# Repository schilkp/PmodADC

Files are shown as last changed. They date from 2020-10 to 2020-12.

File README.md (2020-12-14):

# PmodADC

### Philipp Schilk, 2020

## Description
A fully discrete 14bit, 41kHz, Successive-Approximation Audio ADC and 14bit 41kHz R2R Audio DAC 
controlled by an [iCEBreaker FPGA board](https://1bitsquared.com/collections/fpga/products/icebreaker). 

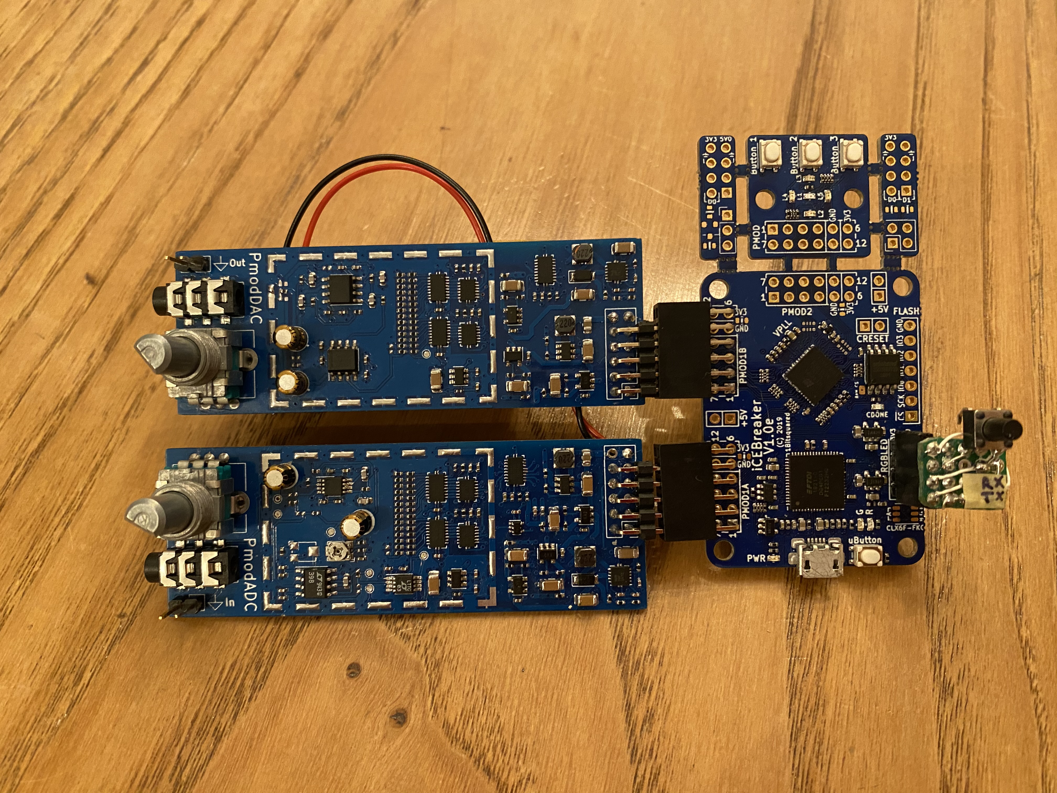
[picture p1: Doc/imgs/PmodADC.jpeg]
Overview


## Details

## Demos

These are a few demonstrations of the PmodADC and PmodDAC.

For each song, there are 3 files provided:  
    - The original (mono) wav file  
    - The song played back via a phone and recorded on the PmodADC  
    - The song played via the PmodDAC and recorded with a Focusrite Saffire Pro 40 Interface.  

Note that all audio files are provided at 44.1kHz to allow for easier playback:  
The PmodADC demos were played back at 44.1kHz and upsampled from 41kHz after recording.  
The PmodDAC demos were downsampled to 41kHz for playback, and recorded at 44.1kHz.   

All music by Kevin MacLeod, see Music Attribution below.

The wav files can be found [here](Doc/Demos), or via the Soundcloud links below:

| *Song* 	| *Original* 	| *PmodADC Demo* 	| *PmodDAC Demo* 	|
|:-:	|:-:	|:-:	|:-:	|
| New Hero in Town 	| [here](https://soundcloud.com/user-489490213/new-hero-in-town-reference/s-YKGpP2wkpSc) 	| [here](https://soundcloud.com/user-489490213/new-hero-in-town-pmodadc/s-A1OPIKn5Tv4) 	| [here](https://soundcloud.com/user-489490213/new-hero-in-town-pmoddac/s-smGRP41zKKE) 	|
| Protofunk 	| [here](https://soundcloud.com/user-489490213/protofunk-reference/s-mYtDzv4H0rD) 	| [here](https://soundcloud.com/user-489490213/protofunk-pmodadc/s-5CrWlwWIQJU) 	| [here](https://soundcloud.com/user-489490213/protofunk-pmoddac/s-AqIKrZKs7Aa) 	|
| Whiskey on the Mississippi 	| [here](https://soundcloud.com/user-489490213/whiskey-on-the-mississippi-reference/s-0ekaJDO2ERm) 	| [here](https://soundcloud.com/user-489490213/whiskey-on-the-mississippi-pmodadc/s-d2xfiT4uBGa) 	| [here](https://soundcloud.com/user-489490213/whiskey-on-the-mississippi-pmoddac/s-CflAaRhN0gA) 	|
| The Parting 	| [here](https://soundcloud.com/user-489490213/the-parting-reference/s-s09MCjP3SIX) 	| [here](https://soundcloud.com/user-489490213/the-parting-pmodadc/s-gcHSaS2ZzWT) 	| [here](https://soundcloud.com/user-489490213/the-parting-pmoddac/s-kLg3MuZsgWg) 	|

Alternatively, a single website with all the above audio files can be found [here](https://soundcloud.com/user-489490213/sets/pmodadc-demonstration/s-fJryQAe7XSp).

## Setup

A guide to setting up the open-source [apio](https://github.com/FPGAwars/apio) tool-chain can be found [here](Doc/ToolchainSetup.md).   

This project requires some hardware modifications to the iCEbreaker board. See [here](Doc/iCEBreakerMod.md) for details.  

The Python/Matlab scripts to play and record audio require some drivers and setup. See [here](Doc/FT2232H_Setup.md) for details.  

Two versions of the Verilog Code are provided:  
	- Setup 1, which immediately plays back the audio recorded by the PmodADC via the PmodDAC.  
	- Setup 2, which allows the PmodADC and PmodDAC to send/receive audio via USB.
	
See [here](iCEbreaker_HDL/Setup%20Description.md) for details.

## Python Utilities

The easiest way to record and play music is using the two python utilities provided [here](Scripts/Python/).

They rely on numpy, pyserial, wavio, and scipy:

```bash
> pip install -r requirements.txt
```

They have only been tested under python3.

### Record.py

Record music to a wav file using the PmodADC.

By default the audio is resampled to 44.1kHz.

Usage:

```
usage: Record.py [-h] (-s S | -n N | -i) [-r] comport outfile

positional arguments:
  comport     The COM port to which the board is connected.
  outfile     The filename under which the recorded audio should be saved.

optional arguments:
  -h, --help  show this help message and exit
  -s S        The number of seconds that should be recorded.
  -n N        The number of samples that should be recorded.
  -i          Recorded until a Keyboard Interrupt is received.
  -r          Do not re-sample audio to 44.1khz.
```

Record 10 seconds of audio from COM8 and save it to recording.wav:

```bash
python3 Record.py COM8 recording.wav -s 10
```

### Play.py

Play a wav file via the PmodDAC.

By default the wav file is resampled to 41kHz (if necessary). 

Usage:
```
usage: Play.py [-h] [-L | -R] [-r] comport wavfile

positional arguments:
  comport     The COM port to which the board is connected.
  wavfile     The filename of the audio file.

optional arguments:
  -h, --help  show this help message and exit
  -L          Play the left audio channel.
  -R          Play the right audio channel.
  -r          Do not re-sample audio to 41kHz.
```

Play the left channel of some_audio_file.wav via COM8:

```bash
python3 Play.py COM8 some_audio_file.wav -L
```

## Matlab Utilities

Matlab functions to communicate with the PmodADC/PmodDAC are also provided. 

See [Scripts/MATLAB/RecordAudioExample.m](Scripts/MATLAB/RecordAudioExample.m) and [Scripts/MATALB/PlayAudioExample.m](Scripts/MATALB/PlayAudioExample.m)

## Music Attribution

```
Protofunk by Kevin MacLeod  
Link: https://incompetech.filmmusic.io/song/4247-protofunk  
License: http://creativecommons.org/licenses/by/4.0/  

Whiskey on the Mississippi by Kevin MacLeod  
Link: https://incompetech.filmmusic.io/song/4624-whiskey-on-the-mississippi  
License: http://creativecommons.org/licenses/by/4.0/  
  
New Hero In Town by Kevin MacLeod  
Link: https://incompetech.filmmusic.io/song/5742-new-hero-in-town  
License: http://creativecommons.org/licenses/by/4.0/  

The Parting by Kevin MacLeod  
Link: https://incompetech.filmmusic.io/song/4501-the-parting  
License: http://creativecommons.org/licenses/by/4.0/  
```

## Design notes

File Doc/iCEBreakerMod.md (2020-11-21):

# iCEBreaker Mod
# Hardware Modifications

Everything done to the iCEBreaker board. 

(Note: This is based on my v1.0e iCEBreaker board. I don't know if this is any different for other versions)

## Isolate FIFO Interface

To be able to transmit all audio data, the FT2232H is used in FIFO mode.
Because this uses many pins in common with the PMOD2 connector, the devices on the break-off
section may interfere with the communication. 

Therefore the break-off section should either be broken-off, or the disconnected 
by removing the 2 Resistor Networks indicated below:

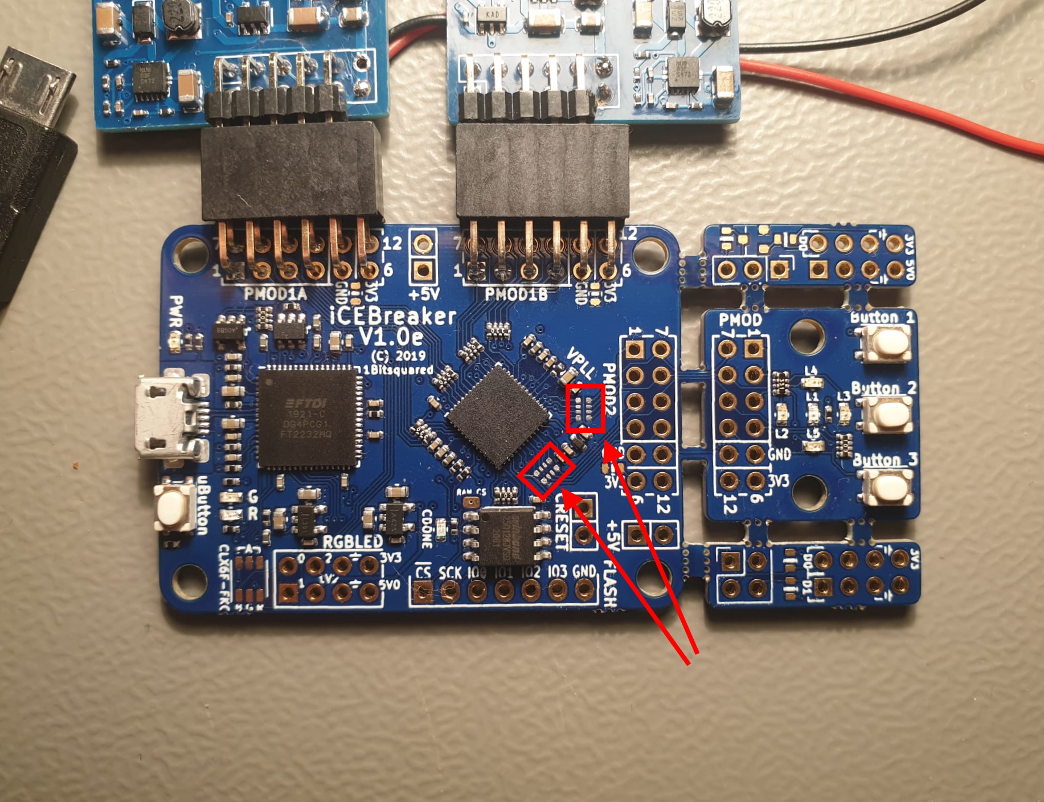
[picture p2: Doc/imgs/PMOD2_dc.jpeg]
Resistor Networks to be removed


To be fair, I don't know if this would actually be a problem. I did not test it. 

## Connect FIFO Interface

The FIFO needs to be connected to the FPGA using the (labelled) solder jumpers on the back side of the board.
Two of them are already connected by default for UART communication. 

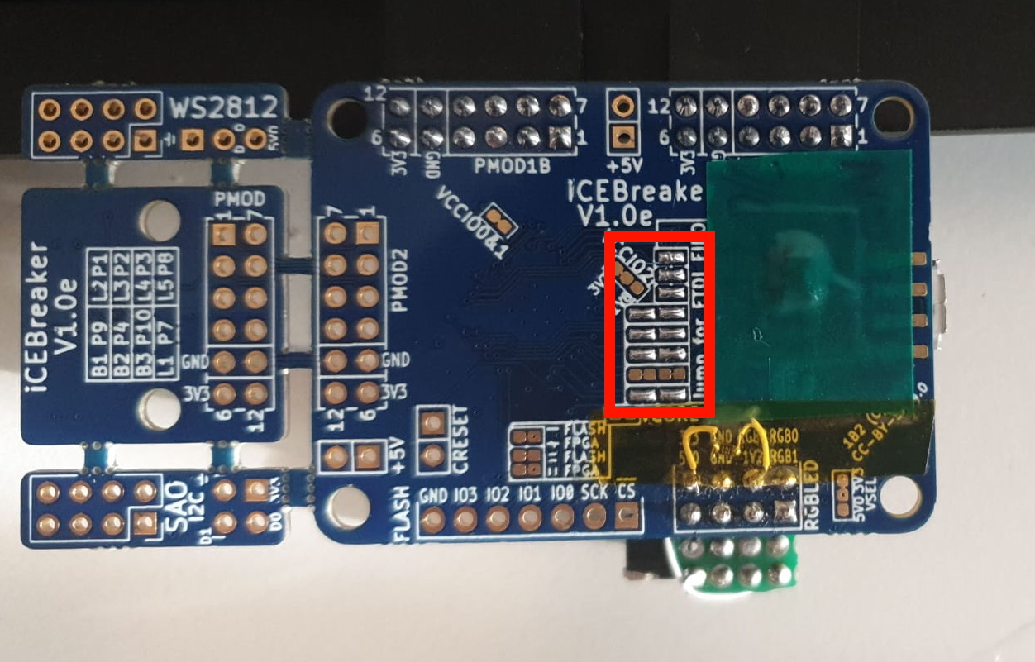
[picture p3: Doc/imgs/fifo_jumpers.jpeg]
FIFO Jumpers


## Add Reset Pull-up

Because the uButton conflicts with the FIFO interface, it cannot be used as a reset button.
As there is no other GPIO left, the RGBLED port is used for additional connectivity.

The pin to which a reset button may be connected requires a pull-up, so that the project
will still function without anything attached to this port.

A 10K pull-up between the '2' Pin and '3V3' can easily be attached to the backside:

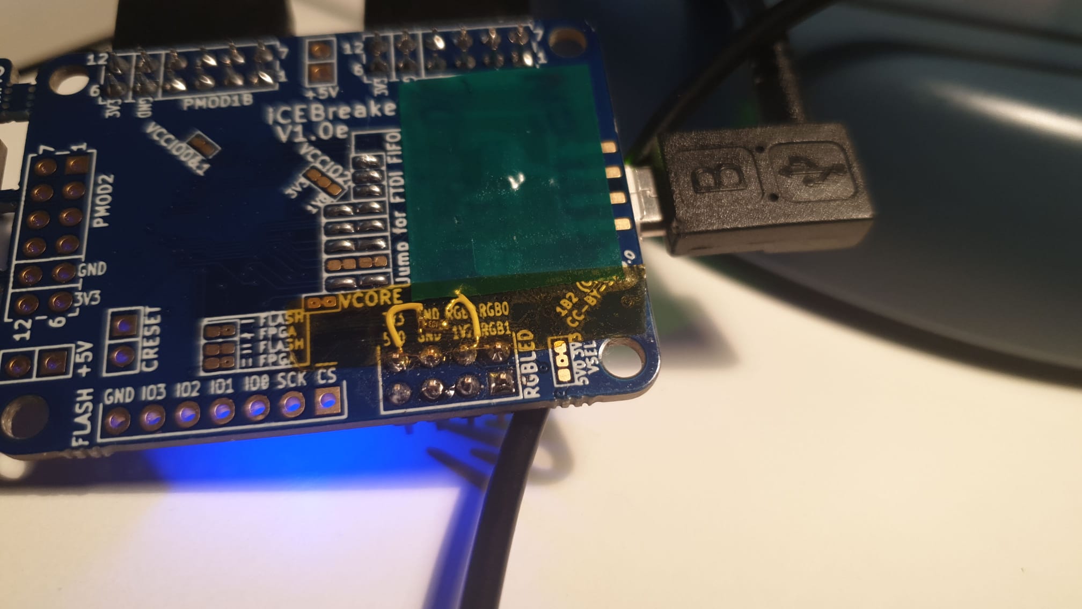
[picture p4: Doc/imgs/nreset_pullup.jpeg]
Additional 10K Pull-Up Resistor


## Optional Reset Button and Status LEDs
A small board may optionally be constructed and attached to the RGBLED connector to 
add a manual reset button and a RX Error and TX Error LED.

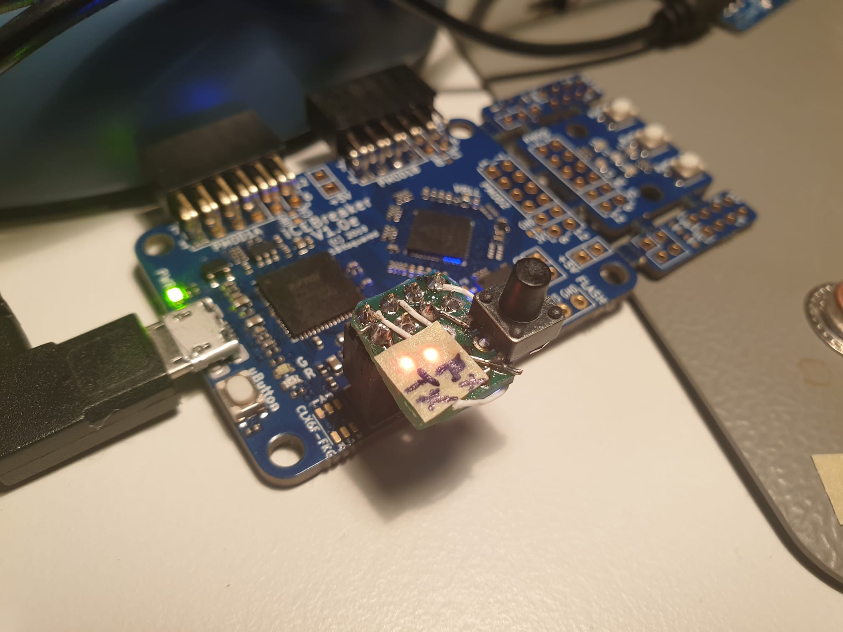
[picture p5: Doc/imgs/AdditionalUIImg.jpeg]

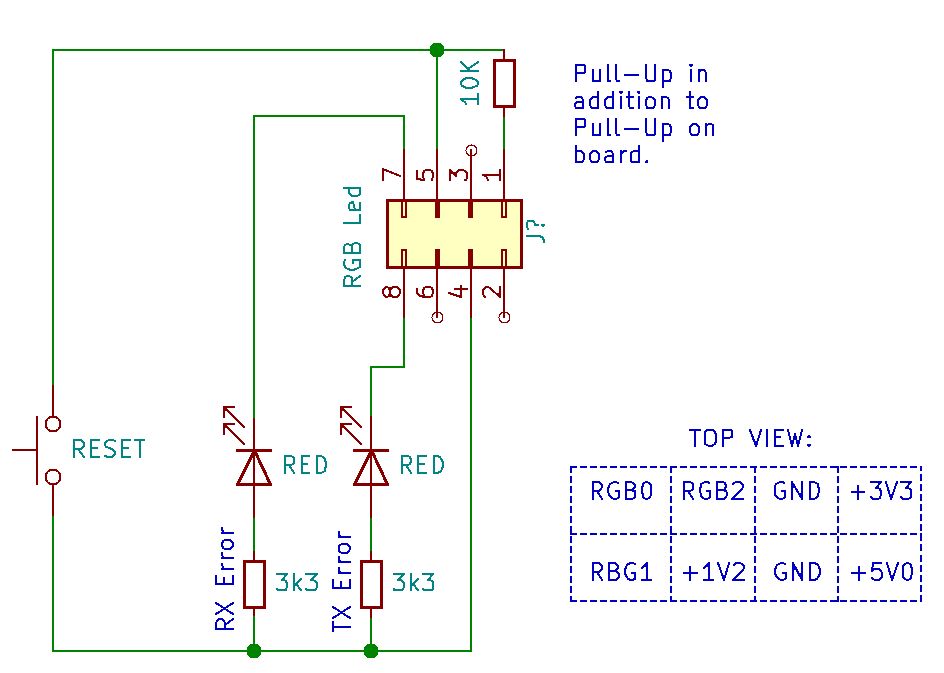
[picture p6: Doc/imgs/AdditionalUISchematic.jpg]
Schematic


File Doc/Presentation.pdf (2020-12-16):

# A DISCRETE SAR ADC/DAC

### Philipp Schilk HS2020

### P&S “iCEBreaker FPGA For IoT Sensing Systems”

### Center for Project Based Learning / ETH Zuerich

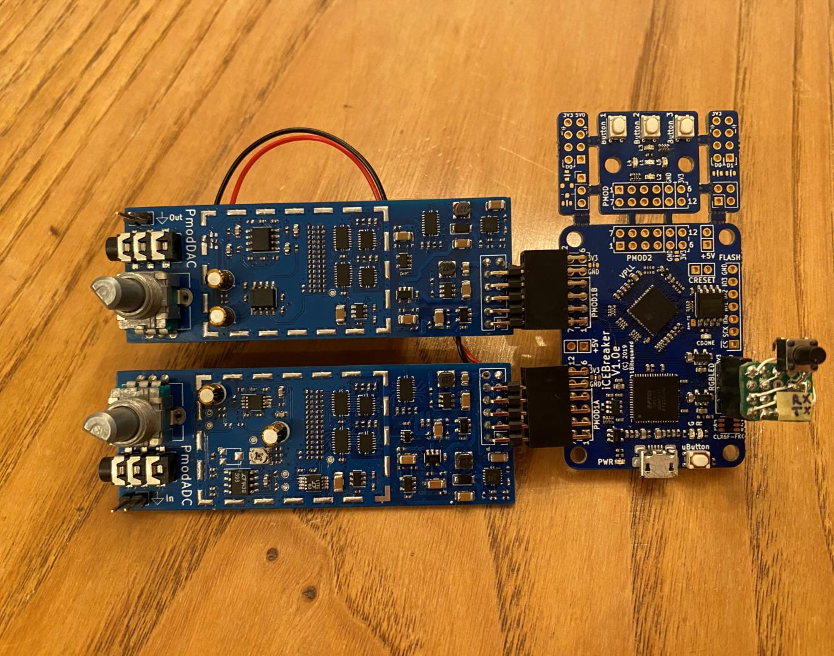
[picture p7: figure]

# Overview

- ADC and DAC
- 14bit Resolution
- 41kHz Sample Rate
- Custom Circuit and Hardware
- Realtime Bidirectional USB Communication
- Python Scripts for Recording and Playback
- MATLAB Scripts for Recording, Playback, and Characterization

# Operating Principle

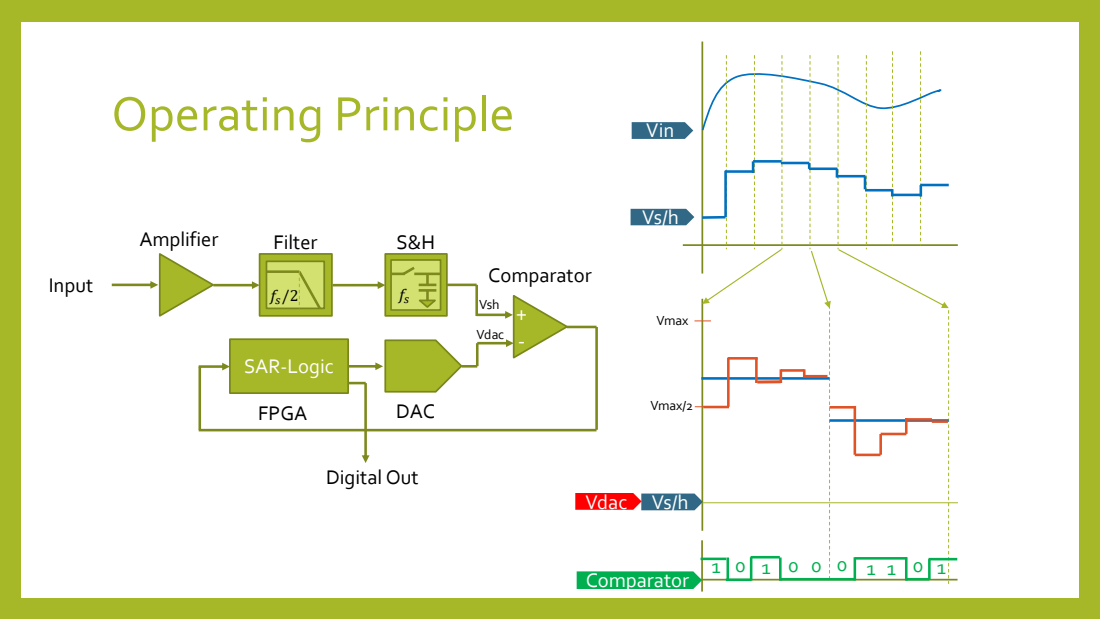
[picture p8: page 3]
Amplifier; Filter; DAC; Comparator; SAR-Logic; Input; FPGA; Digital Out; Vin; Vdac Vs/h; Vdac; Vsh; Vmax; Vmax/2

# Hardware Implementation

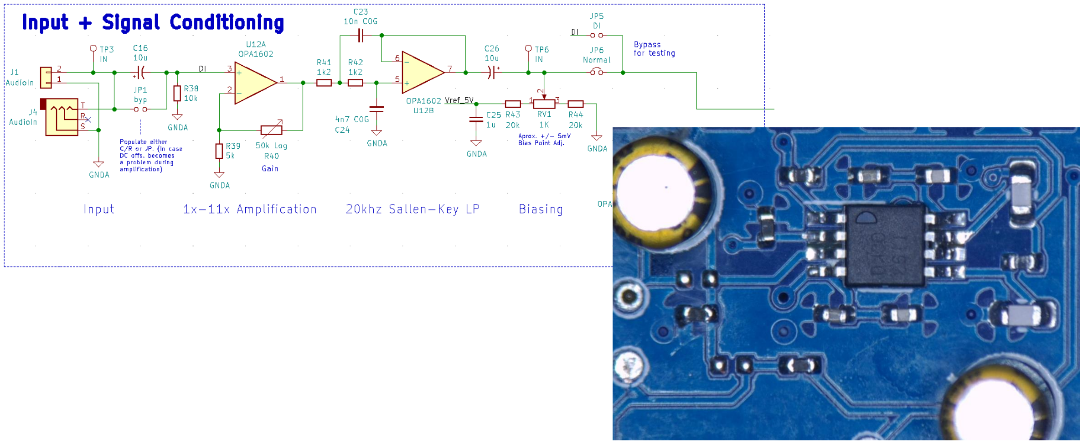
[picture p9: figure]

# Hardware Implementation

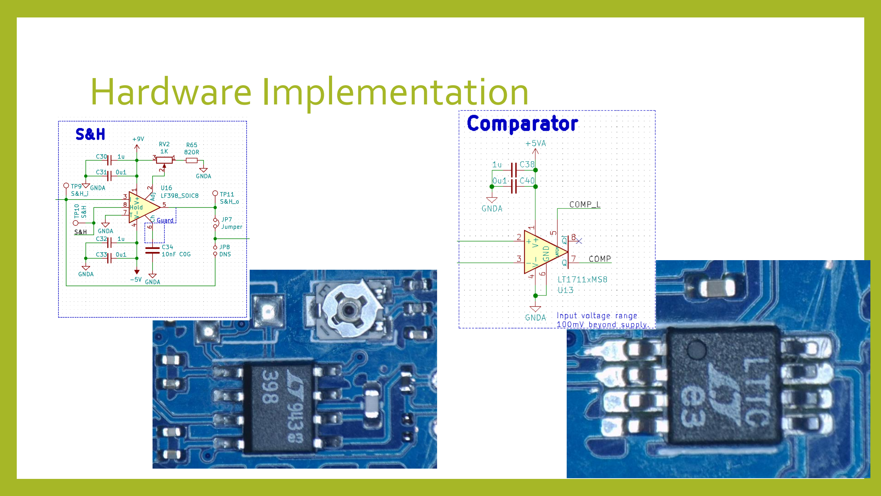
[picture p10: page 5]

# Hardware Implementation

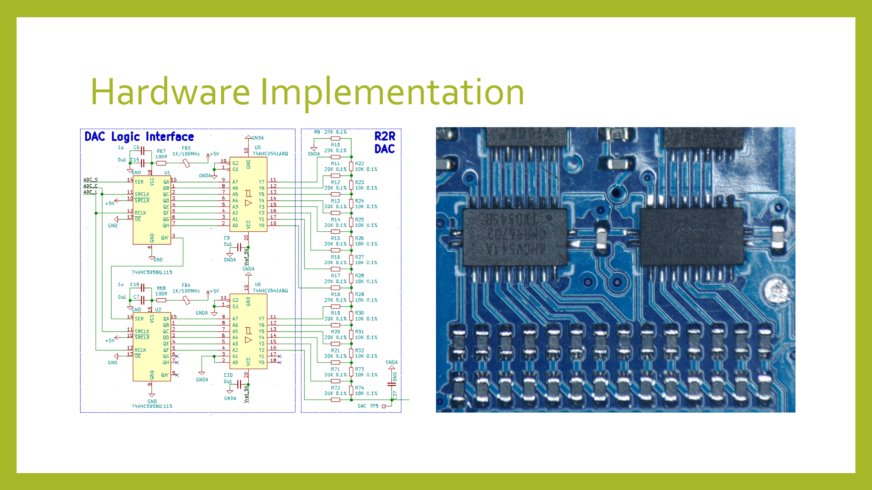
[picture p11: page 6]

# Construction

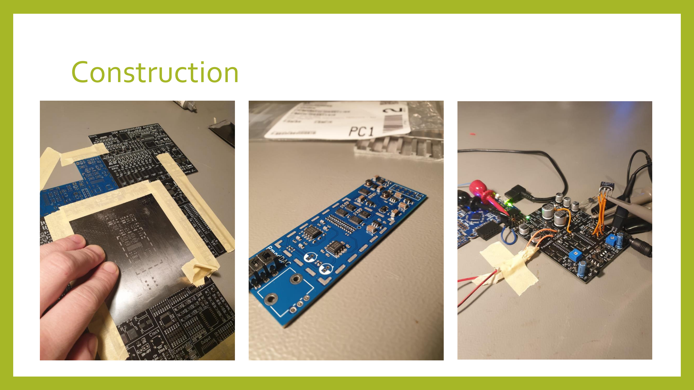
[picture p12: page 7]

# Verilog Implementation

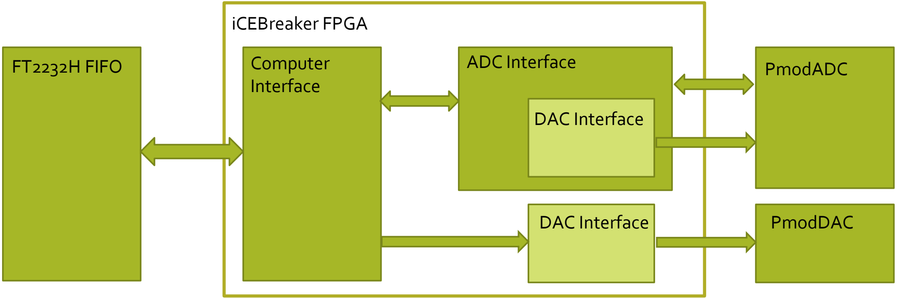
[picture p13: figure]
Computer Interface; ADC Interface; DAC Interface; PmodADC; PmodDAC; FT2232H FIFO; iCEBreaker FPGA

# Verilog Implementation: DAC Interface

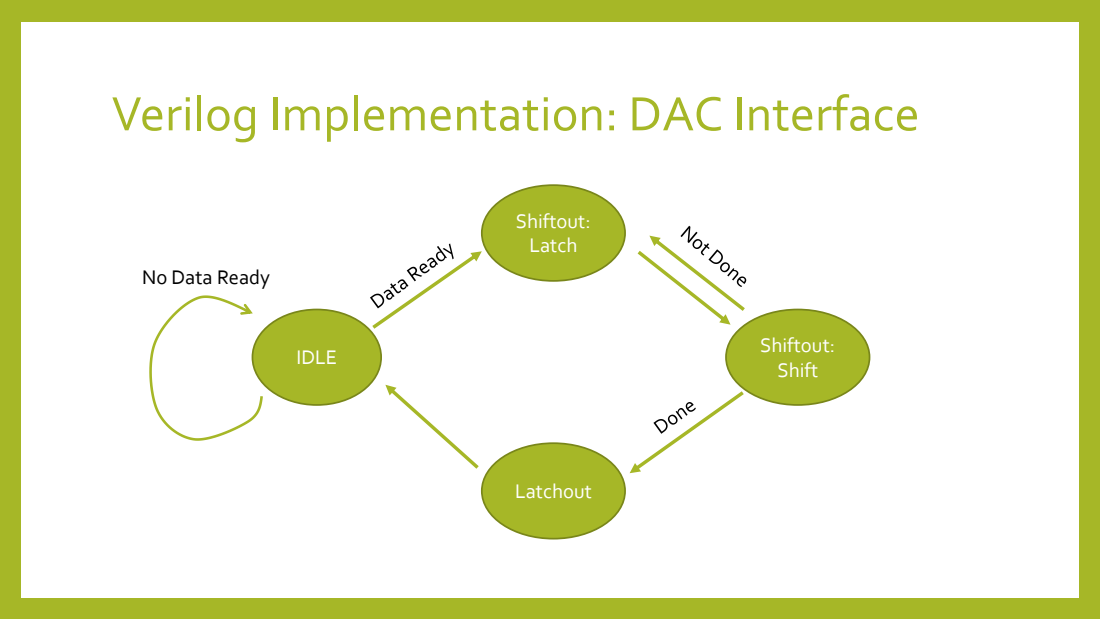
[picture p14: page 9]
IDLE; Shiftout:; Shift; Shiftout: Latch; Latchout

No Data Ready

# Verilog Implementation: ADC Interface

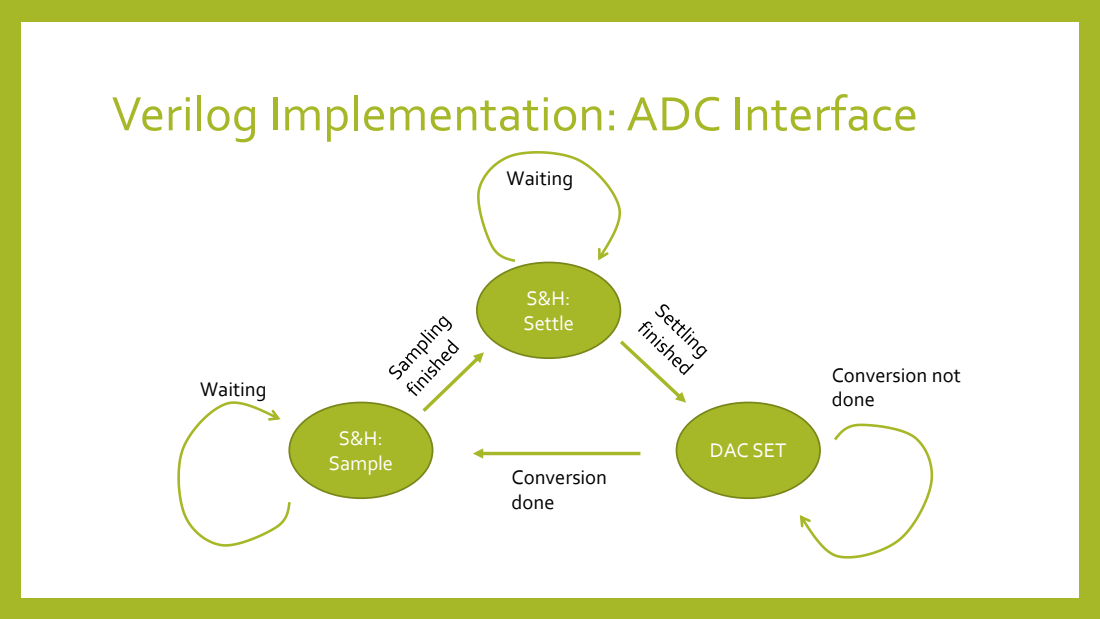
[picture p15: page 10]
S&H: Sample; S&H: Settle; DAC SET; Waiting; Conversion done; Conversion not done

# Verilog Implementation: Computer Interface

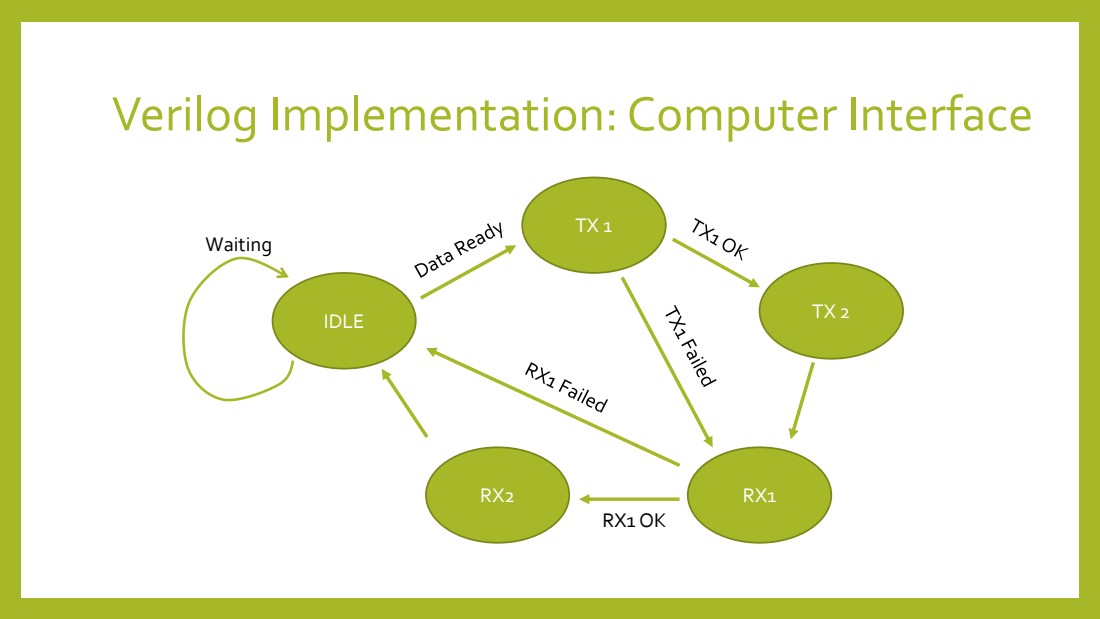
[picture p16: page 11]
IDLE; Waiting

# Operation

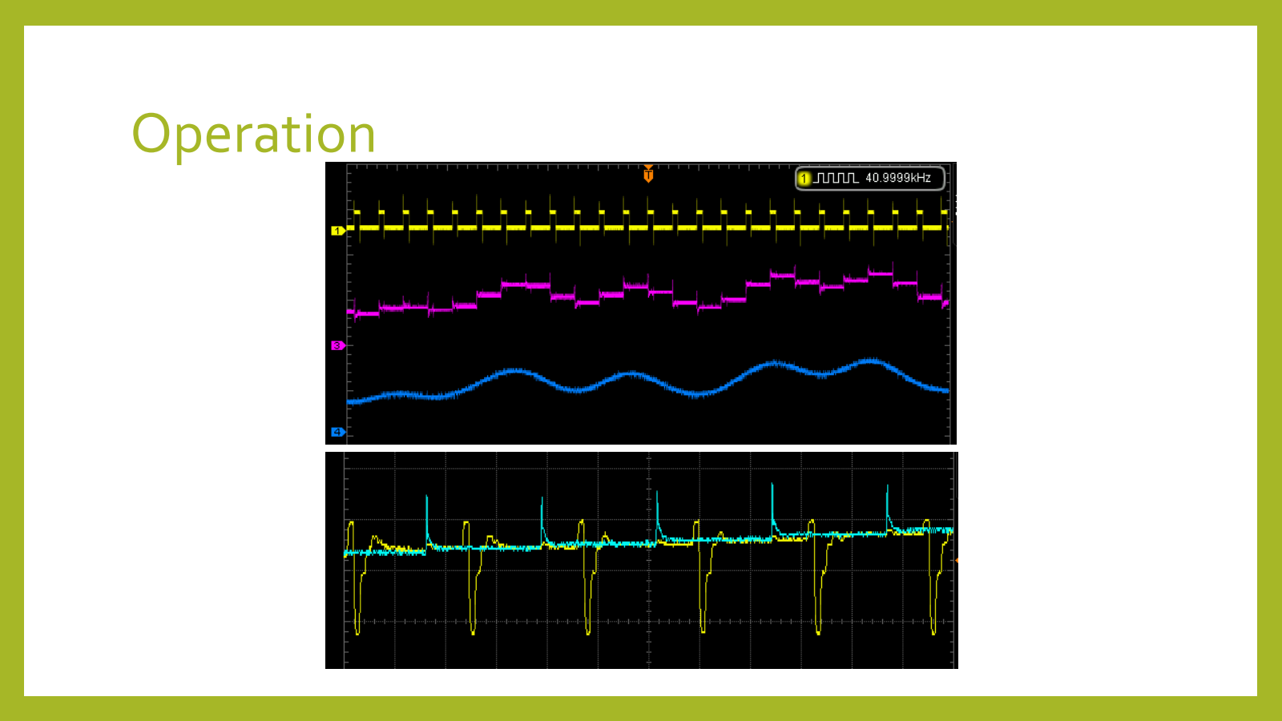
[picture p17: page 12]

# Demonstration

# Demonstration

### - https://github.com/TheSchilk/PmodADC

## - https://soundcloud.com/user-489490213/sets/pmodadc-demonstration/s-

fJryQAe7XSp (https://soundcloud.com/user-489490213/sets/pmodadc-demonstration/s-fJryQAe7XSp)

Song | Original | PmodADC Demo | PmodDAC Demo
New Hero in Town | here (https://soundcloud.com/user-489490213/new-hero-in-town-reference/s-YKGpP2wkpSc) | here (https://soundcloud.com/user-489490213/new-hero-in-town-pmodadc/s-A1OPIKn5Tv4) | here (https://soundcloud.com/user-489490213/new-hero-in-town-pmoddac/s-smGRP41zKKE)
Protofunk | here (https://soundcloud.com/user-489490213/protofunk-reference/s-mYtDzv4H0rD) | here (https://soundcloud.com/user-489490213/protofunk-pmodadc/s-5CrWlwWIQJU) | here (https://soundcloud.com/user-489490213/protofunk-pmoddac/s-AqIKrZKs7Aa)
Whiskey on the Mississippi | here (https://soundcloud.com/user-489490213/whiskey-on-the-mississippi-reference/s-0ekaJDO2ERm) | here (https://soundcloud.com/user-489490213/whiskey-on-the-mississippi-pmodadc/s-d2xfiT4uBGa) | here (https://soundcloud.com/user-489490213/whiskey-on-the-mississippi-pmoddac/s-CflAaRhN0gA)
The Parting | here (https://soundcloud.com/user-489490213/the-parting-reference/s-s09MCjP3SIX) | here (https://soundcloud.com/user-489490213/the-parting-pmodadc/s-gcHSaS2ZzWT) | here (https://soundcloud.com/user-489490213/the-parting-pmoddac/s-kLg3MuZsgWg)

# Characterization

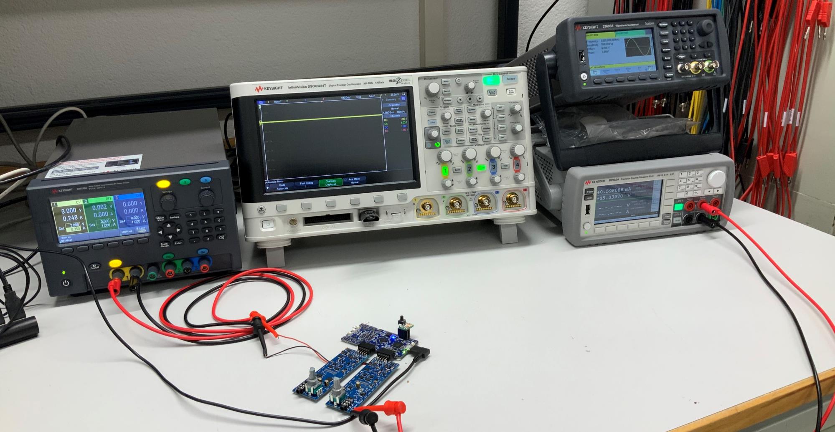
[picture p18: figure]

# Characterization Results

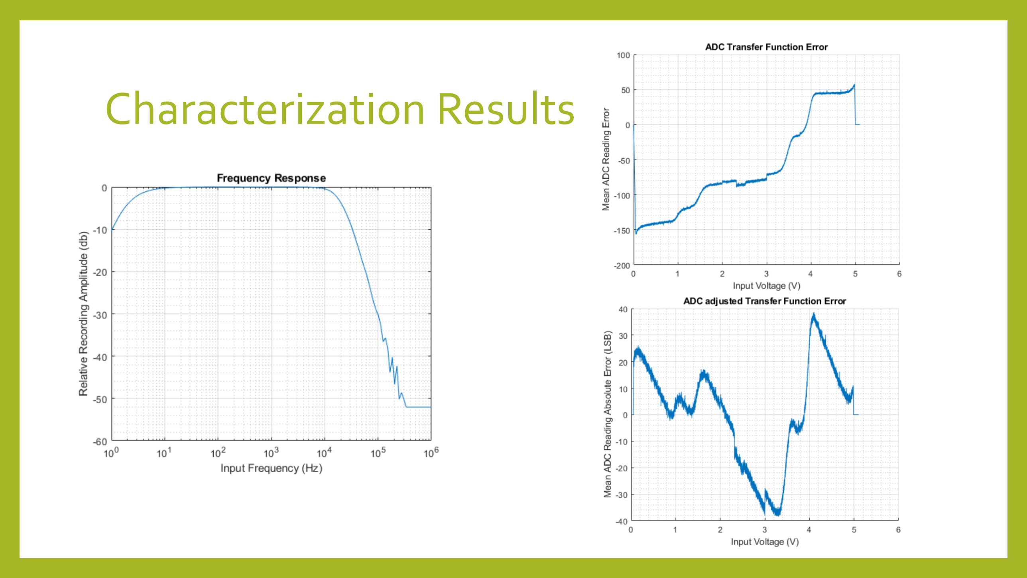
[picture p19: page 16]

# Characterization Results

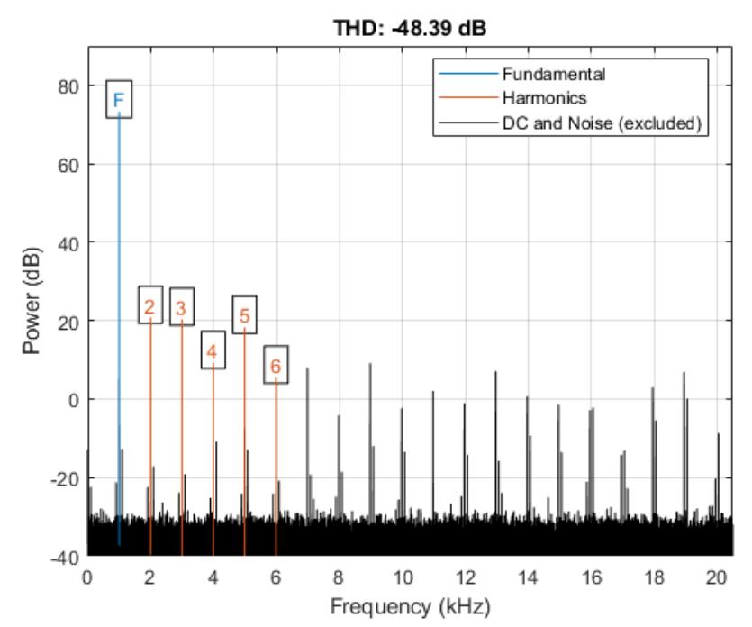
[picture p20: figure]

# Characterization Results

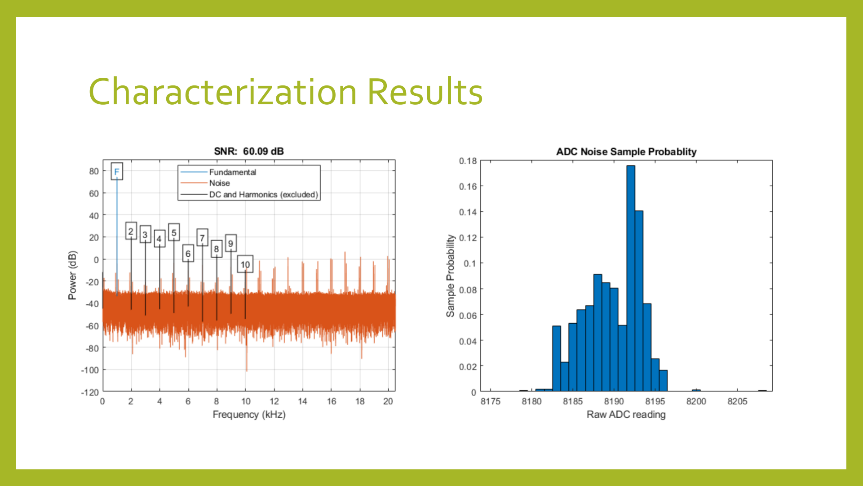
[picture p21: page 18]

### - Comparison Recordings:

- https://soundcloud.com/user-489490213/sets/pmodadc-demonstration/s-fJryQAe7XSp

### - All Design Files, Code, Scripts, Characterization Reports, Documentation, … :

- https://github.com/TheSchilk/PmodADC
- In Particular:
- KiCAD Projects
- Schematics/Gerbers (https://github.com/TheSchilk/PmodADC/tree/master/ProductionFiles)
- Verilog
- Characterization Results (https://github.com/TheSchilk/PmodADC/tree/master/Characterization )
- Interface Scripts

# Thank you!

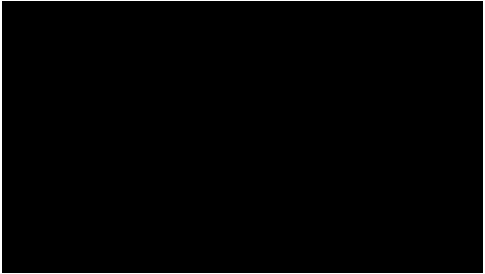
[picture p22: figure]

### - Questions?

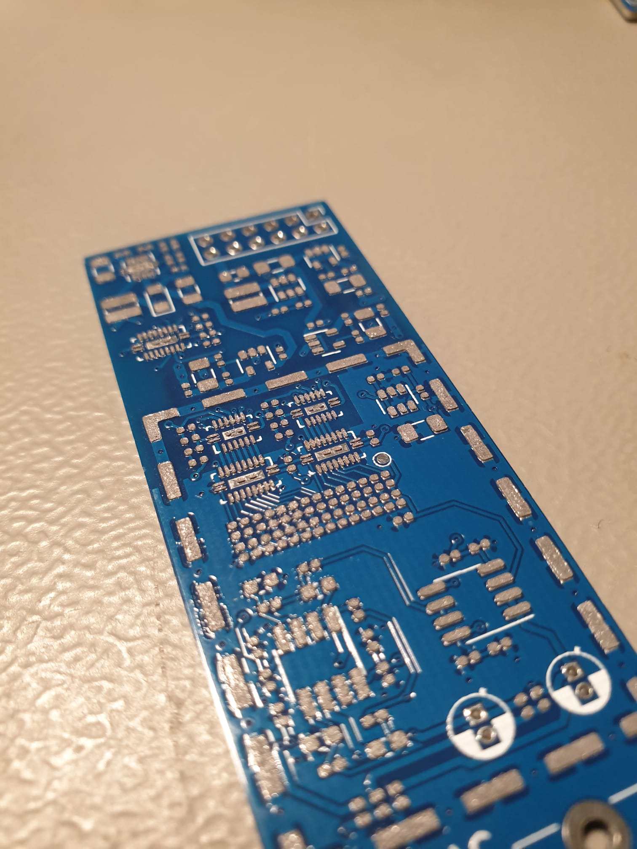
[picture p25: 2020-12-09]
Doc/imgs/v0.1_paste.jpeg

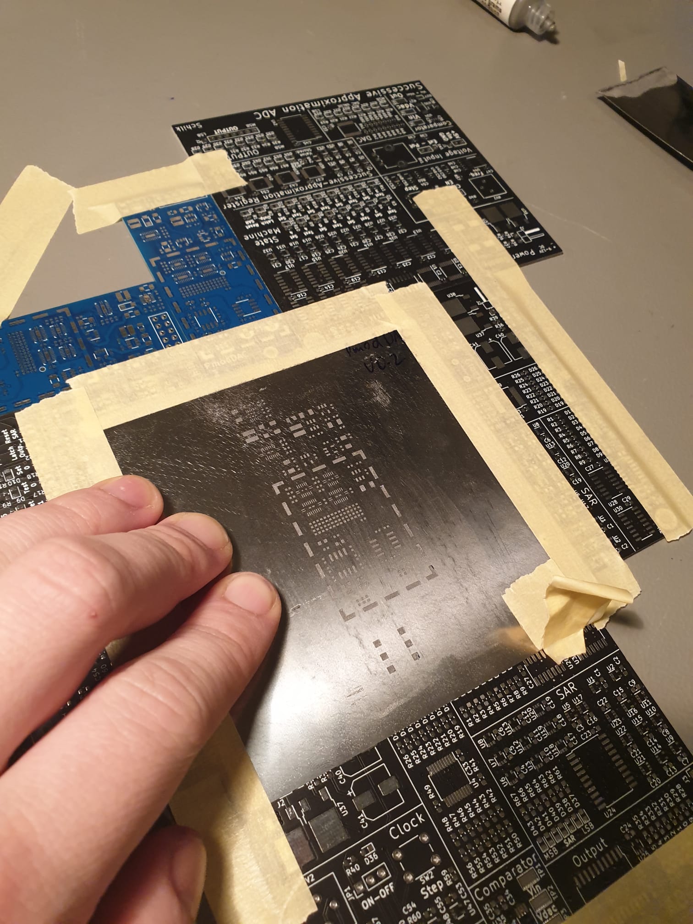
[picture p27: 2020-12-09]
Doc/imgs/v0.1_stencil.jpeg

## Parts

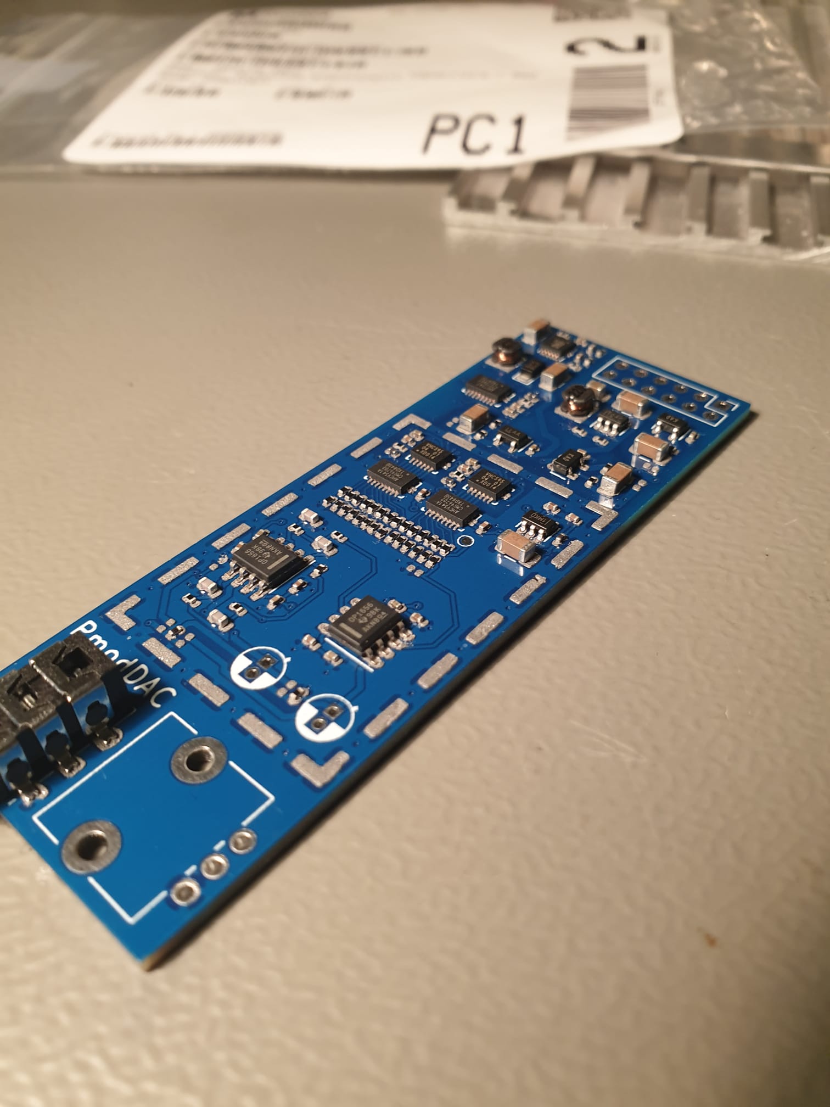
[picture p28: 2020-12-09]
Doc/imgs/Components_placed.jpeg

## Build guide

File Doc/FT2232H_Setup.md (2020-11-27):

# Driver Install

Install the [FTDI VCP driver](https://www.ftdichip.com/Drivers/VCP.htm).

Select the 'setup executable' from the 'Comments' column. 

# FT_Prog Install

Install the [FT_PROG Utility](https://www.ftdichip.com/Support/Utilities.htm#FT_PROG).

# FT2232H Config

 - Open the FT_PROG Utility.
 - Press *F5* to scan for devices
 - Find the iCEBreaker's FTDI Chip
	- Identifiable by property 'Product Desc'='iCEBreaker V1.0e'
 - Set Port B to FIFO
	- Device -> FT EEPROM -> Hardware Specific -> *Port B* -> Hardware, select '245 FIFO'
 - Press *Ctrl-P* to program the FT2232H

# Driver Config
 - Find the Virtual COM port in Windows' Device Manager, right click, select 'Properties'
 - Under the 'Port Settings' tab, select 'Advanced' 
 - Set both the Transmit and Receive buffer size to '256', and the latency timer to '2ms'
 - Click OK

# Re-install libUSB for iCEBreaker
For apio to be able to program the Device after this step,
you will have to re-replace the driver with libUSB:

```bash
> apio drivers --ftdi-enable
```

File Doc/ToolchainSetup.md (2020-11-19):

# Toolchain Setup notes

A quick guide on how to setup the open-source [APIO](https://github.com/FPGAwars/apio) tool-chain for the [iCEbreaker](https://1bitsquared.com/collections/fpga/products/icebreaker) FPGA board under *Windows*.

## Installation and Build

###	Prerequisites

 - A working python3 environment.

### Toolchain install
First, install the apio toolchain:
```bash
> pip install -U apio
> apio install --all
```

### USB Drivers
With the board connected, the USB drivers can be installed. 
This will have to be redone if the board is connected to a 
different USB port. 

```bash
> apio drivers --ftdi-enable
```

In the pop-up, find the board ('iCEBreaker (Interface 0)') and
replace the driver with 'libusb' using the labeled button.

Once this is completed, reconnect the board.

### Build and upload
To verify the verilog code:
```bash
> apio verify
```

To build:
```bash
> apio build
```

To verify, build, upload:
```bash
> apio upload
```

### Analyze
To do a timing analysis:
```bash
> apio time
```

To get more information about the build (including FPGA usage):
```bash
> apio build -v
```

To start the simulation (requires a testbench):
```bash
> apio sim
```

## New Project Setup
To initiate a new project in an directory:
```bash
> apio init --board iCEBreaker
```

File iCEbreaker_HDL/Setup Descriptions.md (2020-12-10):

# Setup 1: Mirror
Immediately play back PmodADC capture on PmodDAC.

Connections:
PMOD1A - PmodADC
PMOD1B - PmodDAC

# Setup 2: Audio Interface
Via USB: Transmit audio recorded by PmodADC, and receive audio for PmodDAC. 

Connections:
PMOD1A - PmodADC
PMOD1B - PmodDAC

Note:
Requires FT2232H to be reprogrammed to FIFO mode on Port B. (See Documentation [here](../Doc/FT2232H_Setup.md))
Requires iCEBreaker board to be slight modified. (See Documentation [here](../Doc/iCEBreakerMod.md))
See [here](../Scripts) for all computer-side scripts.

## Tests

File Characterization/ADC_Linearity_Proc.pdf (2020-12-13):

% Load Data
load ADC_Linearity_Data.mat
% Calculate mean and std_dev of each set point data_mean = mean(data')';
data_std = std(double(data'))';
% Plot Transfer Function
figure()
plot(set_point,data_mean);

title('ADC Transfer Function'); grid ON;
grid MINOR;
xlabel('Input Voltage (V)'); ylabel('Mean ADC Reading (LSB)');

% Plot Std. Deviation:
figure()
plot(set_point,data_std);
title('ADC Reading Standard Dev.'); grid ON;
grid MINOR;
xlabel('Input Voltage (V)'); ylabel('ADC Reading Std. Dev.');
% ADC & Ideal Transfer function
ideal_tf = set_point*((2^14-1)/5);
ideal_tf = round(min(2^14-1,max(ideal_tf,0)),1);

figure()
hold on;
plot(set_point,data_mean); plot(set_point,ideal_tf);

title('ADC Transfer Function vs Ideal'); grid ON;
grid MINOR;
xlabel('Input Voltage (V)'); ylabel('Mean ADC Reading (LSB)'); legend('PmodADC','Ideal');

% Error
figure()
hold on;
plot(set_point,data_mean-ideal_tf); title('ADC Transfer Function Error'); grid ON;
grid MINOR;
xlabel('Input Voltage (V)');
ylabel('Mean ADC Reading Error');
% Error to gain/offset adjusted linear transfer function

% Find linear regression of data, skipping saturation regions at beginning

% and end

r = polyfit(set_point(1000:16000), data_mean(1000:16000),1); m = r(1);
b = r(2);

% Calculate new linear regression
lin_tf = double(set_point)*m+b;
lin_tf = max(0,min(lin_tf,2^14-1)); % Saturate lin_tf = round(lin_tf,0);

figure()
hold on;
plot(set_point,data_mean); plot(set_point,lin_tf);

title('ADC Transfer Function vs Adjusted Ideal '); grid ON;
grid MINOR;
xlabel('Input Voltage (V)');
ylabel('Mean ADC Reading (LSB)'); legend('PmodADC','Ideal');

% Error
figure()
hold on;
plot(set_point,data_mean-lin_tf);
title('ADC adjusted Transfer Function Error'); grid ON;
grid MINOR;
xlabel('Input Voltage (V)');
ylabel('Mean ADC Reading Absolute Error (LSB)');

Published with MATLAB® R2020b

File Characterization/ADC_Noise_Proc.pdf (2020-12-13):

load ADC_Noise_Data.mat;
noise_mean = mean(data);
noise_max = max(data);
noise_min = min(data);
noise_span = noise_max - noise_min; noise_std = std(double(data));

disp('Mean Reading: ');
disp(noise_mean);

disp('Max Reading: ');
disp(noise_max);

disp('Min Reading: ');
disp(noise_min);

disp('Span of Readings: '); disp(noise_span);

disp('Std. Deviation of Readings: '); disp(noise_std);
% Plot distribution of sample probablilty
[count, val] = groupcounts(data);
count = count/sum(count);

f1 = figure('Name','ADC Noise Sample Probablity'); bar(val, count, 1);
title('ADC Noise Sample Probablity');
xlabel('Raw ADC reading');
ylabel('Sample Probability');

f2 = figure('Name','ADC Noise Sample Probablity (Log)'); bar(val, count, 1);
title('ADC Noise Sample Probablity (Log)');
xlabel('Raw ADC reading');
ylabel('Sample Probability (Log)'); set(gca, 'YScale', 'log');

Mean Reading:
8.1898e+03

Max Reading:
8208

Min Reading:
8175

Span of Readings:
33

Std. Deviation of Readings: 3.4353

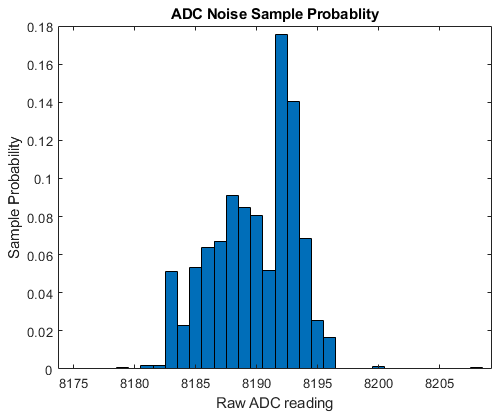
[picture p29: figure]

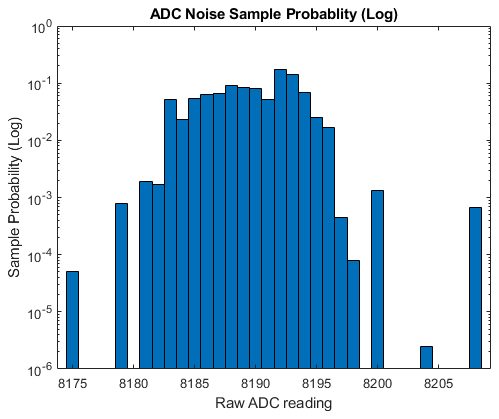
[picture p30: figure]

Published with MATLAB® R2020b

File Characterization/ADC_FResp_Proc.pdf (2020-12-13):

load ADC_FResp_Data.mat;
% Calculate amplitude:
% I know this is not the most scientific way... ampl = zeros(n_steps);
for i = 1:n_steps
ampl(i) = max(data(i,:))-min(data(i,:)); end

% Calculate relative amplitude:
ampl = ampl/max(ampl);

% Convert to db:
ampl = 20*log10(ampl);
% Plot
figure();
semilogx(set_point, ampl); title('Frequency Response') grid ON;
grid MINOR;
xlabel('Input Frequency (Hz)'); ylabel('Relative Recording Amplitude (db)');

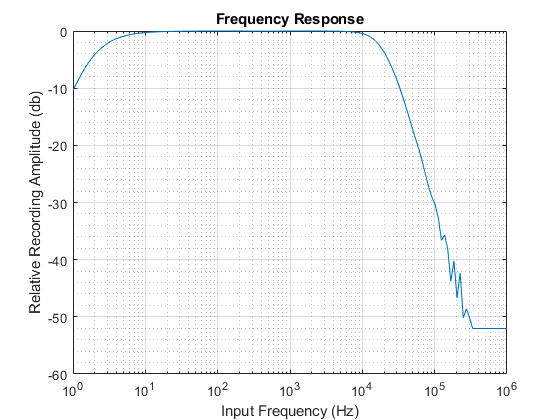
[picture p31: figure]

Published with MATLAB® R2020b

1

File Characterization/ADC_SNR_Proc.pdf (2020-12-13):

load ADC_SNR_Data.mat;
snr(double(data),fs,10);

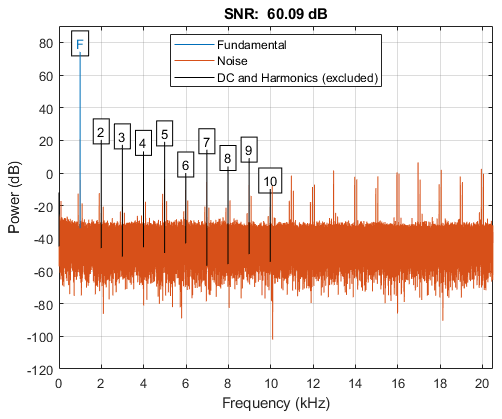
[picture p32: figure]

Published with MATLAB® R2020b

1

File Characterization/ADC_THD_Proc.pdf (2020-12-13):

load ADC_THD_Data.mat;
thd(double(data),41000);

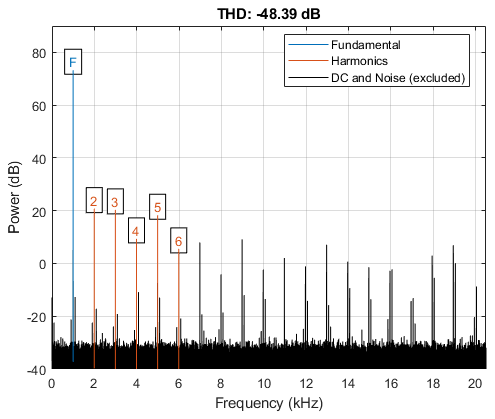
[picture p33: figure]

Published with MATLAB® R2020b

1

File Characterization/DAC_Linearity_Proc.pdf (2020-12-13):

% Load Data
load DAC_Linearity_Data.mat % Plot Transfer Function
figure()
plot(set_point,data);

title('DAC Transfer Function'); grid ON;
grid MINOR;
xlabel('DAC Setting');
ylabel('DAC Output (V)');
% Comparison to ideal transfer function ideal_tf = double(set_point)*(5/(2^14-1)); ideal_tf = min(2^14-1,max(ideal_tf,0));

% Error
figure()
hold on;
plot(set_point,data-ideal_tf); title('DAC Transfer Function Error'); grid ON;
grid MINOR;
xlabel('DAC Setting');
ylabel('Absolute DAC Error (V)');

% Error
figure()
hold on;
plot(set_point,(data-ideal_tf)/(5/(2^14-1))); title('DAC Transfer Function Error');
grid ON;
grid MINOR;
xlabel('DAC Setting');
ylabel('Absolute DAC Error (LSB)');

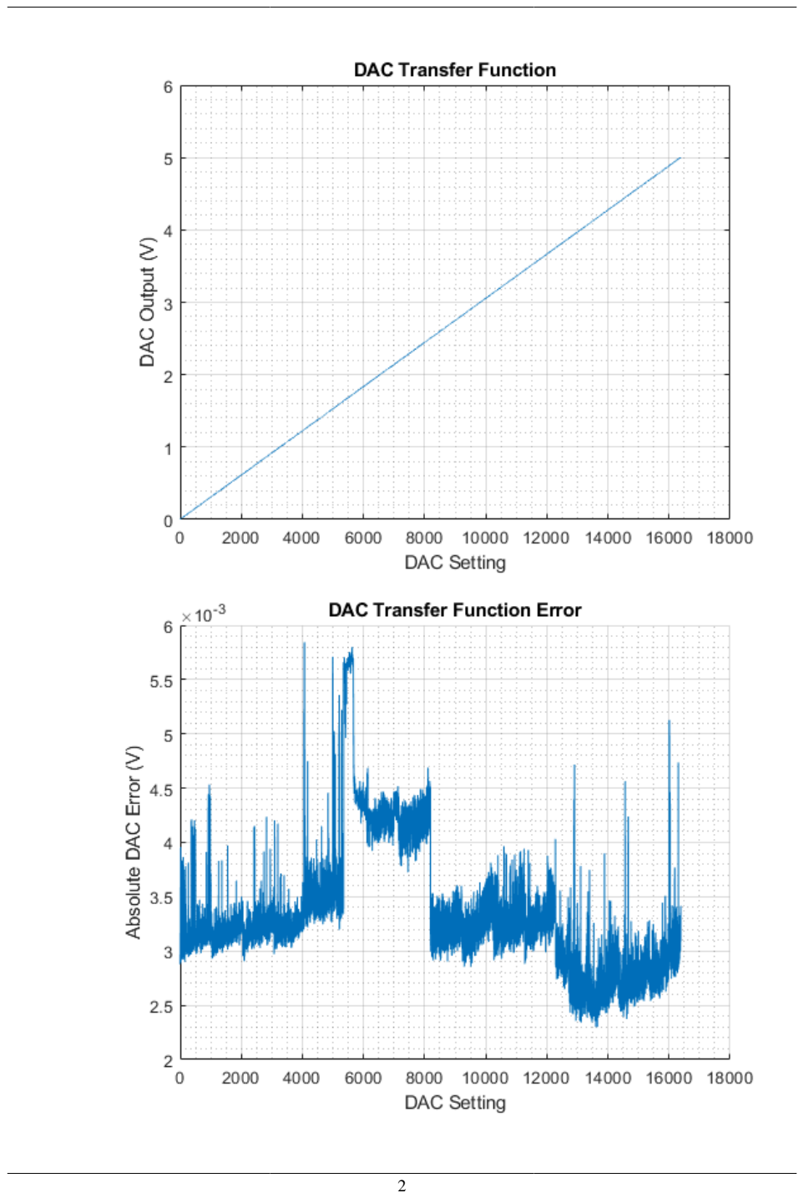
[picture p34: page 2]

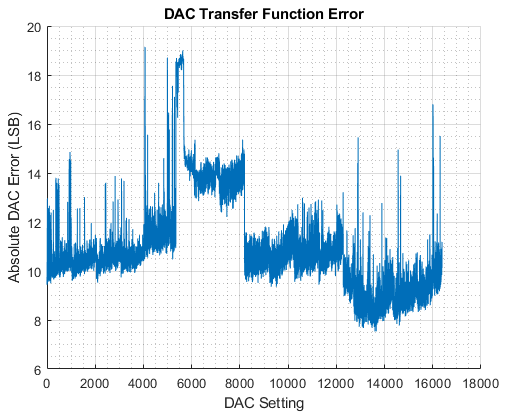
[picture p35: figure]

Published with MATLAB® R2020b

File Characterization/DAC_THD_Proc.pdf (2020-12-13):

load DAC_THD_Data.mat;
thd(y,f_s);

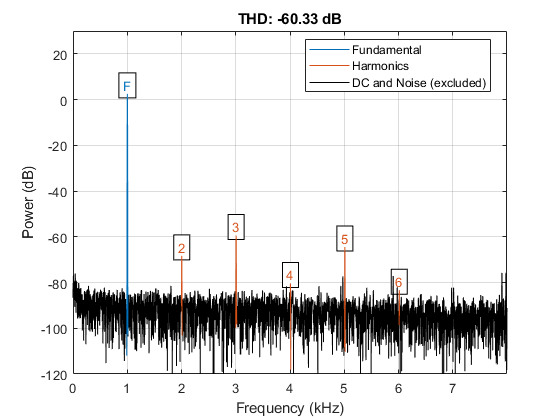
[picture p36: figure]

Published with MATLAB® R2020b

1

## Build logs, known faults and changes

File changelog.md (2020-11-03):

# 0.2
 - Complete Redesign of Power
 - Split DAC and ADC into two boards
 - Changed Reference and Opamps
 - Changed Comparator
 - Changed Volume Pot Size
 - Added Bias Trimming
 - Change S&H offset trim pot size
 - Moved all analog circuitry under shield

# 0.1
 - Changed shiftregister due to availability issues.
 - Added Level Shifter

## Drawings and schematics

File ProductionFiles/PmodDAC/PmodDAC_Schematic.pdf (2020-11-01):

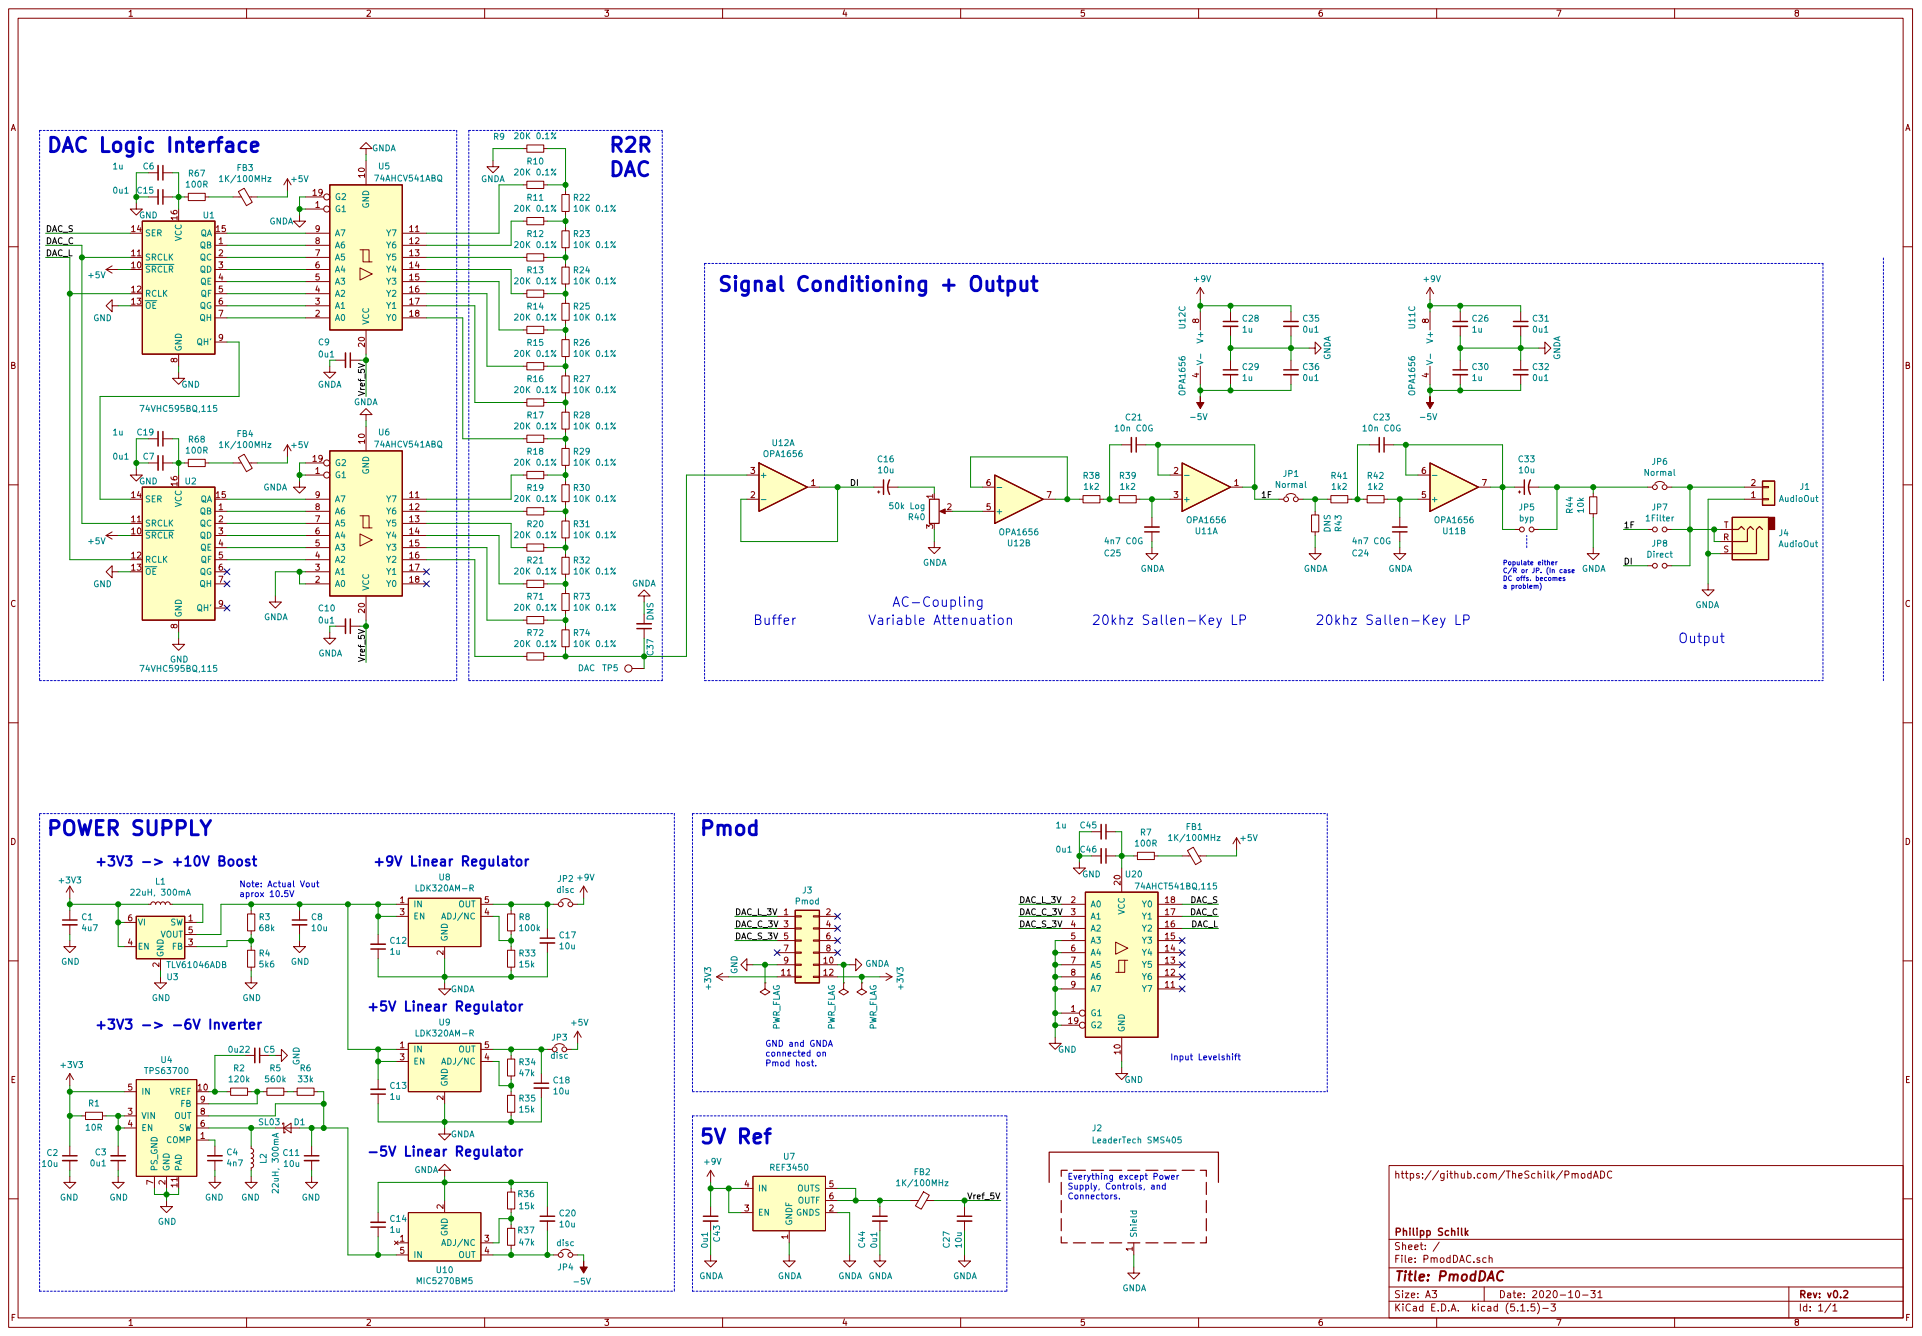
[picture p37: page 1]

Output Populate either C/R or JP. (In case DC offs. becomes a problem) POWER SUPPLY

Note: Actual Vout aprox 10.5V

2 EN 3 ADJ/NC 4 OUT 5 U8
LDK320AM-R

2 FB 3 EN 4 VOUT 5 VI 6 U3TLV61046ADB

connected on Pmod host. +3V3 -> -6V Inverter

2 EN 3 ADJ/NC 4 OUT 5 U9

Input Levelshift GND and GNDA

Everything except Power
Supply, Controls, and Connectors.

https://github.com/TheSchilk/PmodADC

File: PmodDAC.sch Sheet: / Philipp Schilk

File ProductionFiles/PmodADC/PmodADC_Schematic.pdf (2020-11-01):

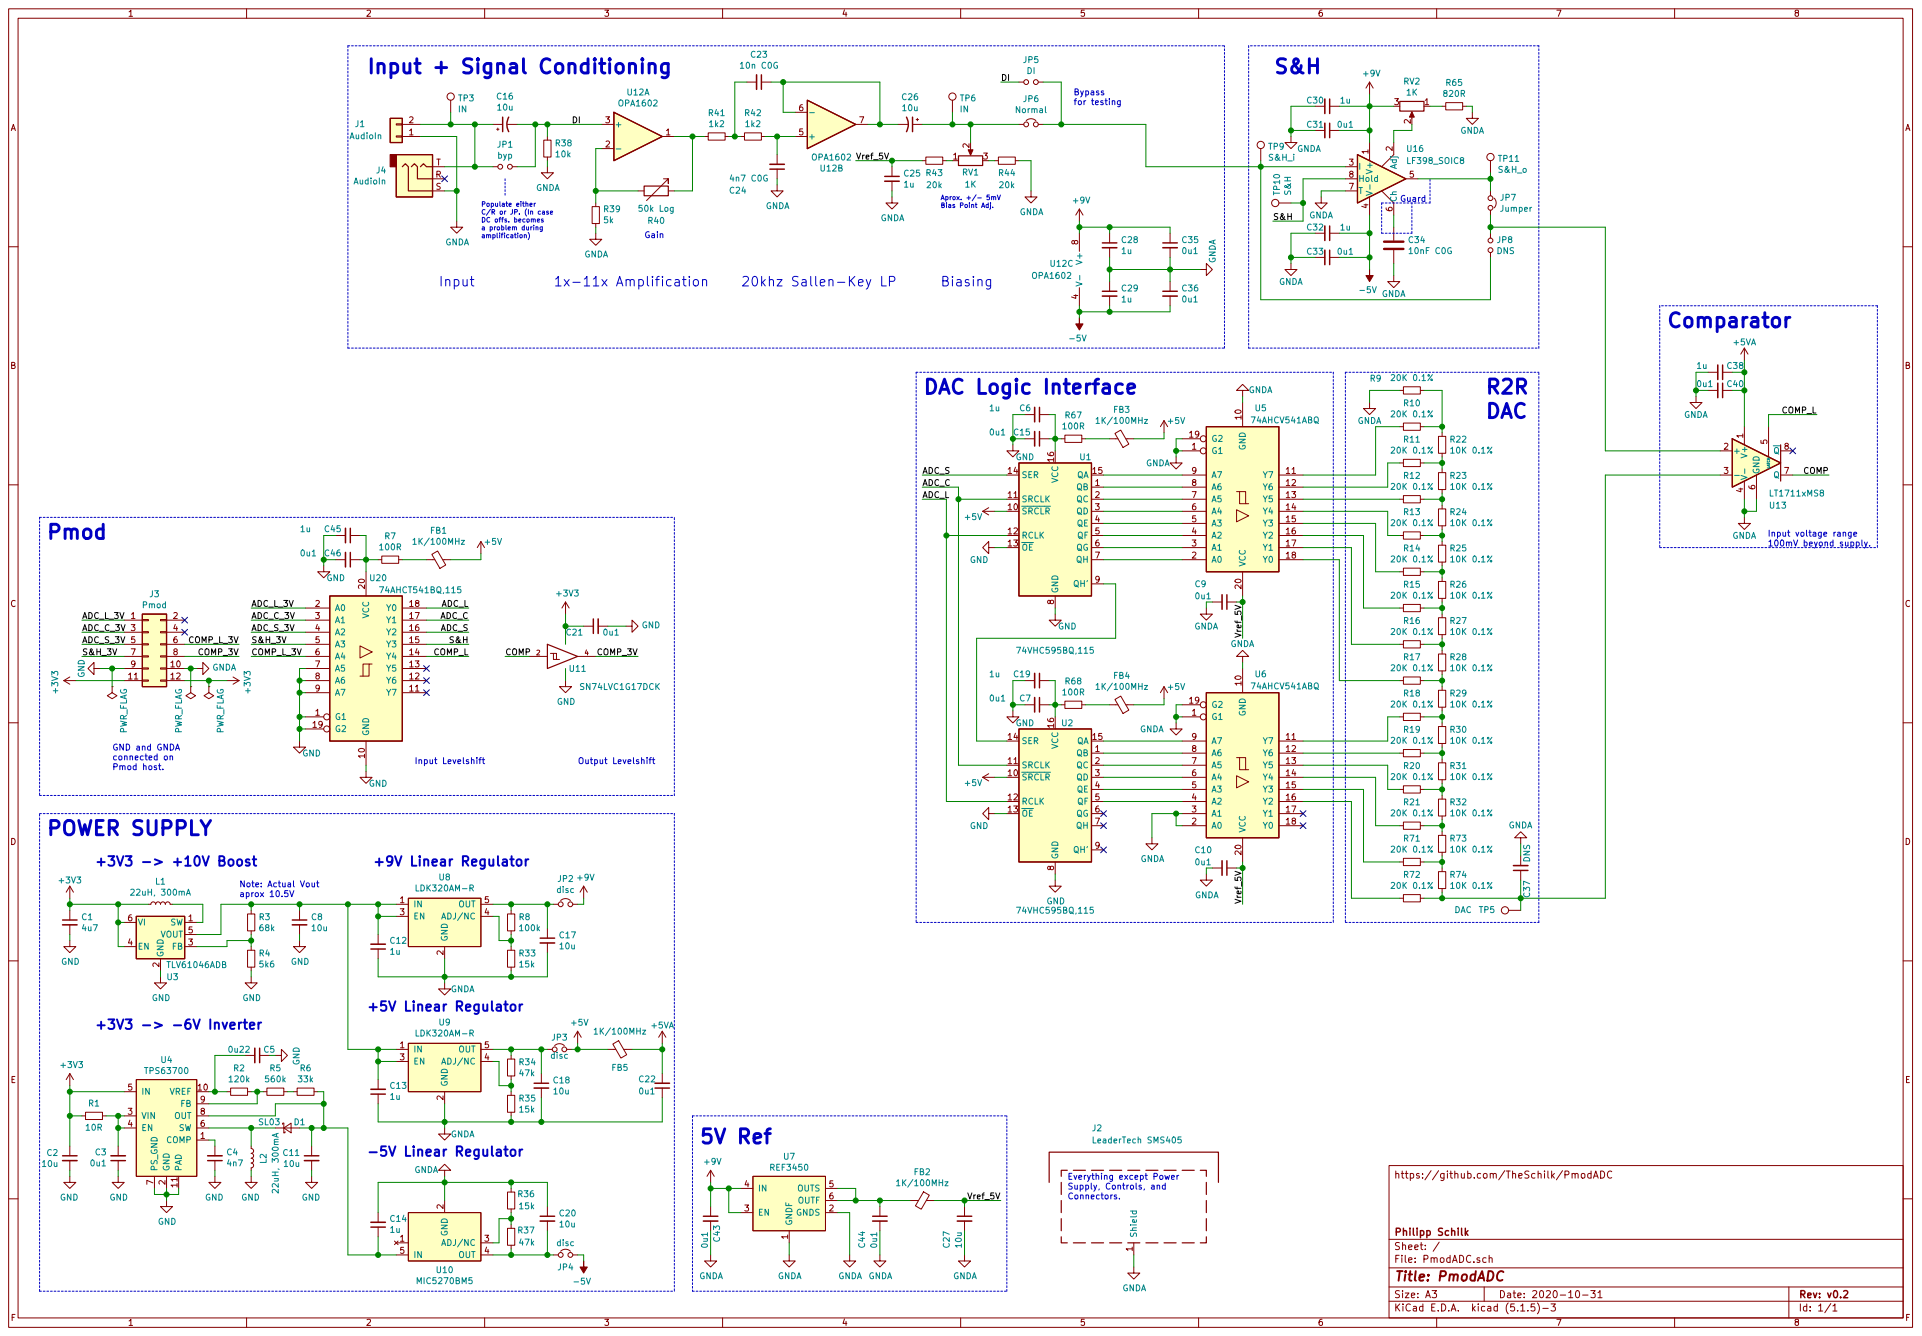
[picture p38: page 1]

2 FB 3 EN 4 VOUT 5 VI 6 U3TLV61046ADB TP10 S&H
Guard +3V3 -> +10V Boost

GND and GNDA
connected on Pmod host.

Note: Actual Vout aprox 10.5V

2 EN 3 ADJ/NC 4 OUT 5 U9
LDK320AM-R

Supply, Controls, and Connectors. 5V Ref

https://github.com/TheSchilk/PmodADC

File: PmodADC.sch Sheet: / Philipp Schilk

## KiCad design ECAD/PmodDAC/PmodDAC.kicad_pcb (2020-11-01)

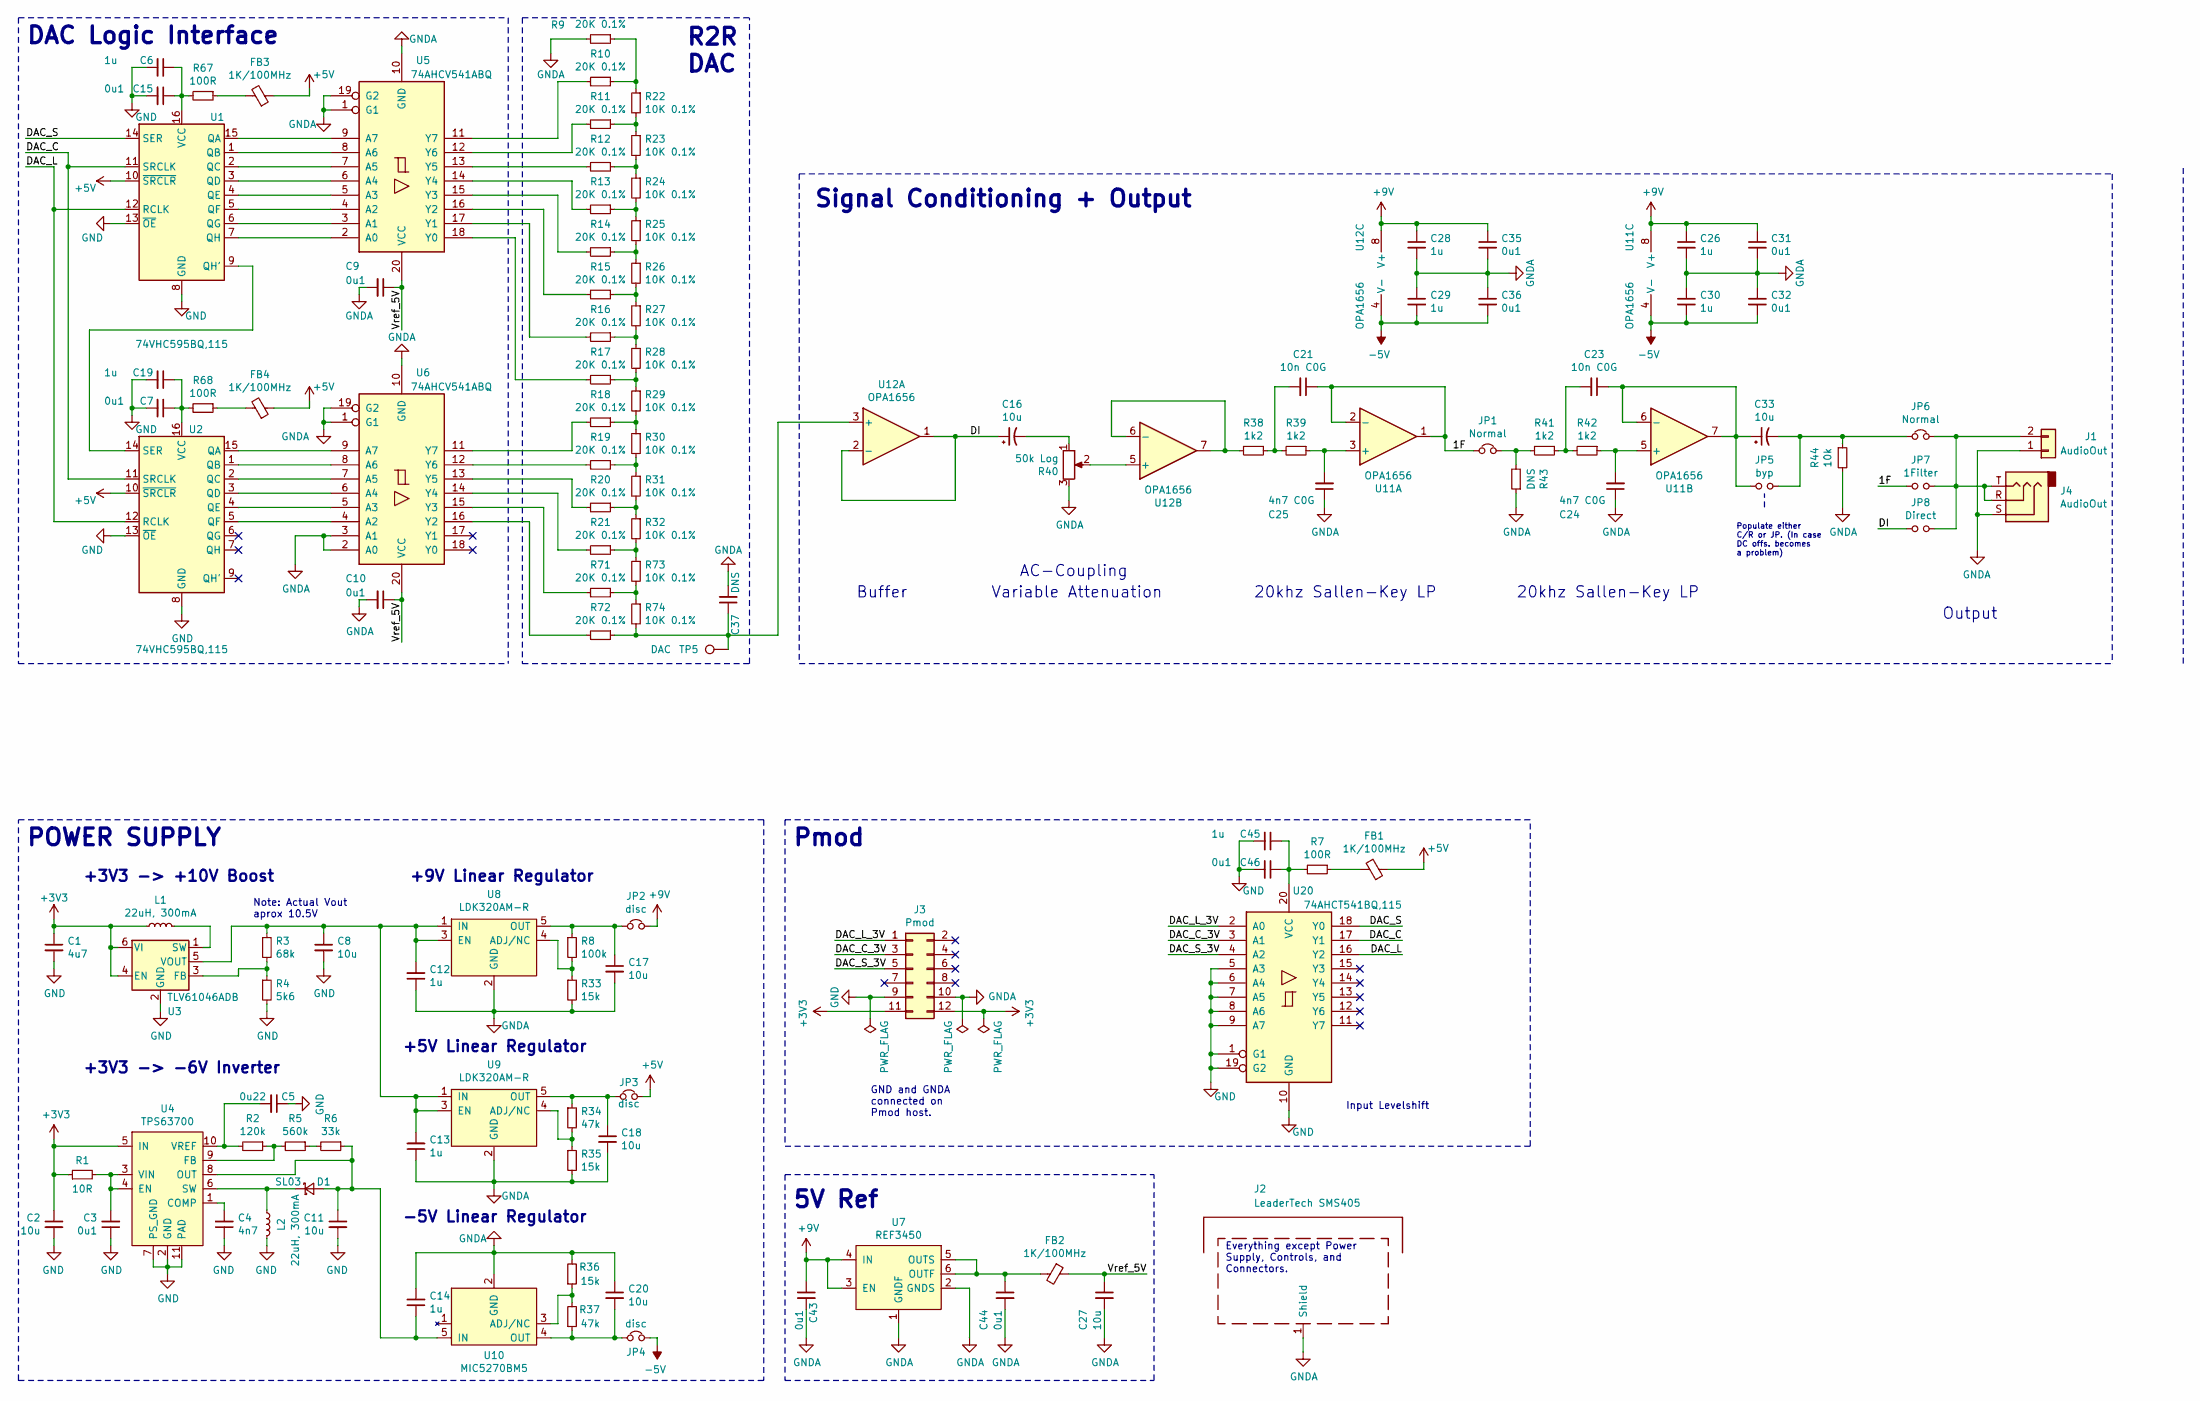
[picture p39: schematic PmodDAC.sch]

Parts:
C1: 4u7; C_0805_2012Metric
C2, C8, C11, C17, C18, C20, C27: 10u; C_1206_3216Metric
C3, C7, C9, C10, C15, C31, C32, C35, C36, C43, C44, C46: 0u1; C_0402_1005Metric
C4: 4n7; C_0402_1005Metric
C5: 0u22; C_0402_1005Metric
C6, C12, C13, C14, C19, C26, C28, C29, C30, C45: 1u; C_0402_1005Metric
C16, C33: 10u; CP_Radial_D4.0mm_P1.50mm
C21, C23: 10n C0G; C_0603_1608Metric
C24, C25: 4n7 C0G; C_0603_1608Metric
C37: DNS; C_0402_1005Metric
D1: SL03; D_SMF
FB1, FB2, FB3, FB4: 1K/100MHz; L_0402_1005Metric
J1: AudioOut; PinHeader_1x02_P2.54mm_Vertical
J2: LeaderTech SMS405; Leader_SMS405
J3: Pmod; PinHeader_2x06_P2.54mm_Vertical
J4: AudioOut; PJ-313D-6A
JP1, JP6: Normal; R_0402_1005Metric
JP2, JP3, JP4: disc; R_0402_1005Metric
JP5: byp; R_0402_1005Metric
JP7: 1Filter; R_0402_1005Metric
JP8: Direct; R_0402_1005Metric
L1, L2: 22uH, 300mA; L_Wuerth_MAPI-3020
R1: 10R; R_0402_1005Metric
R2: 120k; R_0402_1005Metric
R3: 68k; R_0402_1005Metric
R4: 5k6; R_0402_1005Metric
R5: 560k; R_0402_1005Metric
R6: 33k; R_0402_1005Metric
R7, R67, R68: 100R; R_0402_1005Metric
R8: 100k; R_0402_1005Metric
R9, R10, R11, R12, R13, R14, R15, R16, R17, R18, R19, R20, R21, R71, R72: 20K 0.1%; R_0402_1005Metric
R22, R23, R24, R25, R26, R27, R28, R29, R30, R31, R32, R73, R74: 10K 0.1%; R_0402_1005Metric
R33, R35, R36: 15k; R_0402_1005Metric
R34, R37: 47k; R_0402_1005Metric
R38, R39, R41, R42: 1k2; R_0402_1005Metric
R40: 50k Log; Potentiometer_Alps_RK09L_Single_Vertical
R43: DNS; R_0402_1005Metric
R44: 10k; R_0402_1005Metric
TP5: DAC; TestPoint_Pad_D1.0mm
U1, U2: 74VHC595BQ,115; SOT763-1_DHVQFN16
U3: TLV61046ADB; SOT-23-6
U4: TPS63700; VSON-10-1EP_3x3mm_P0.5mm_EP1.65x2.4mm_ThermalVias
U5, U6: 74AHCV541ABQ; SOT764-1_DHVQFN20
U7: REF3450; SOT-23-6
U8, U9: LDK320AM-R; SOT-23-5
U10: MIC5270BM5; SOT-23-5
U11, U12: OPA1656; SOIC-8_3.9x4.9mm_P1.27mm
U20: 74AHCT541BQ,115; SOT764-1_DHVQFN20

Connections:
+3V3: C1.1, C2.1, J3.11, J3.12, L1.1, R1.1, U3.4 (EN), U3.6 (VI), U4.5 (IN)
+5V: FB1.1, FB3.1, FB4.1, JP3.2, U1.10 (~SRCLR), U2.10 (~SRCLR)
+9V: C26.1, C28.1, C31.1, C35.1, C43.1, JP2.2, U7.3 (EN), U7.4 (IN), U11.8 (V+), U12.8 (V+)
-5V: C29.2, C30.2, C32.2, C36.2, JP4.2, U11.4 (V-), U12.4 (V-)
/1F: C21.1, JP1.1, JP7.1, U11.1, U11.2 (-)
/DAC_C: U1.11 (SRCLK), U2.11 (SRCLK), U20.17 (Y1)
/DAC_C_3V: J3.3, U20.3 (A1)
/DAC_L: U1.12 (RCLK), U2.12 (RCLK), U20.16 (Y2)
/DAC_L_3V: J3.1, U20.2 (A0)
/DAC_S: U1.14 (SER), U20.18 (Y0)
/DAC_S_3V: J3.5, U20.4 (A2)
/DI: C16.1, JP8.1, U12.1, U12.2 (-)
/Vref_5V: C9.1, C10.1, C27.1, FB2.1, U5.20 (VCC), U6.20 (VCC)
GND: C1.2, C2.2, C3.1, C4.1, C5.1, C6.2, C7.2, C8.2, C11.2, C15.2, C19.2, C45.2, C46.2, J3.9, L2.2, R4.2, U1.8 (GND), U1.13 (~OE), U2.8 (GND), U2.13 (~OE), U3.2 (GND), U4.2 (GND), U4.7 (PS_GND), U4.11 (PAD), U20.1 (G1), U20.5 (A3), U20.6 (A4), U20.7 (A5), U20.8 (A6), U20.9 (A7), U20.10 (GND), U20.19 (G2)
GNDA: C9.2, C10.2, C12.1, C13.1, C14.2, C17.2, C18.2, C20.1, C24.1, C25.1, C26.2, C27.2, C28.2, C29.1, C30.1, C31.2, C32.1, C35.2, C36.1, C37.2, C43.2, C44.2, J1.1, J2.1, J3.10, J4.S, R9.2, R33.2, R35.2, R36.2, R40.3, R43.1, R44.2, U5.1 (G1), U5.10 (GND), U5.19 (G2), U6.1 (G1), U6.2 (A0), U6.3 (A1), U6.10 (GND), U6.19 (G2), U7.1 (GNDF), U7.2 (GNDS), U8.2 (GND), U9.2 (GND), U10.2 (GND)
unnamed: C3.2, R1.2, U4.3 (VIN), U4.4 (EN)
unnamed: C4.2, U4.1 (COMP)
unnamed: C5.2, R2.2, U4.10 (VREF)
unnamed: C11.1, C14.1, D1.2 (A), R6.1, U4.8 (OUT), U10.5 (IN)
unnamed: C8.1, C12.2, C13.2, R3.1, U3.5 (VOUT), U8.1 (IN), U8.3 (EN), U9.1 (IN), U9.3 (EN)
unnamed: C6.1, C15.1, R67.2, U1.16 (VCC)
unnamed: C16.2, R40.1
unnamed: C17.1, JP2.1, R8.1, U8.5 (OUT)
unnamed: C18.1, JP3.1, R34.1, U9.5 (OUT)
unnamed: C7.1, C19.1, R68.2, U2.16 (VCC)
unnamed: C20.2, JP4.1, R37.1, U10.4 (OUT)
unnamed: C21.2, R38.1, R39.2
unnamed: C23.1, C33.1, JP5.1, U11.6 (-), U11.7
unnamed: C23.2, R41.1, R42.2
unnamed: C24.2, R42.1, U11.5 (+)
unnamed: C25.2, R39.1, U11.3 (+)
unnamed: C33.2, JP5.2, JP6.1, R44.1
unnamed: C37.1, R72.1, R74.2, TP5.1, U12.3 (+)
unnamed: C44.1, FB2.2, U7.5 (OUTS), U7.6 (OUTF)
unnamed: C45.1, C46.1, R7.2, U20.20 (VCC)
unnamed: D1.1 (K), L2.1, U4.6 (SW)
unnamed: FB1.2, R7.1
unnamed: FB3.2, R67.1
unnamed: FB4.2, R68.1
unnamed: J1.2, J4.R, J4.T, JP6.2, JP7.2, JP8.2
unnamed: JP1.2, R41.2, R43.2
unnamed: L1.2, U3.1 (SW)
unnamed: R2.1, R5.2, U4.9 (FB)
unnamed: R3.2, R4.1, U3.3 (FB)
unnamed: R5.1, R6.2
unnamed: R9.1, R10.1, R22.1
unnamed: R10.2, U5.11 (Y7)
unnamed: R11.1, R22.2, R23.1
unnamed: R11.2, U5.12 (Y6)
unnamed: R12.1, R23.2, R24.1
unnamed: R12.2, U5.13 (Y5)
unnamed: R13.1, R24.2, R25.1
unnamed: R13.2, U5.14 (Y4)
unnamed: R14.1, R25.2, R26.1
unnamed: R14.2, U5.15 (Y3)
unnamed: R15.1, R26.2, R27.1
unnamed: R15.2, U5.16 (Y2)
unnamed: R16.1, R27.2, R28.1
unnamed: R16.2, U5.17 (Y1)
unnamed: R17.1, R28.2, R29.1
unnamed: R17.2, U5.18 (Y0)
unnamed: R18.1, R29.2, R30.1
unnamed: R18.2, U6.11 (Y7)
unnamed: R19.1, R30.2, R31.1
unnamed: R19.2, U6.12 (Y6)
unnamed: R20.1, R31.2, R32.1
unnamed: R20.2, U6.13 (Y5)
unnamed: R21.1, R32.2, R73.1
unnamed: R21.2, U6.14 (Y4)
unnamed: R8.2, R33.1, U8.4 (ADJ/NC)
unnamed: R34.2, R35.1, U9.4 (ADJ/NC)
unnamed: R36.1, R37.2, U10.3 (ADJ/NC)
unnamed: R38.2, U12.6 (-), U12.7
unnamed: R40.2, U12.5 (+)
unnamed: R71.1, R73.2, R74.1
unnamed: R71.2, U6.15 (Y3)
unnamed: R72.2, U6.16 (Y2)
unnamed: U1.1 (QB), U5.8 (A6)
unnamed: U1.2 (QC), U5.7 (A5)
unnamed: U1.3 (QD), U5.6 (A4)
unnamed: U1.4 (QE), U5.5 (A3)
unnamed: U1.5 (QF), U5.4 (A2)
unnamed: U1.6 (QG), U5.3 (A1)
unnamed: U1.7 (QH), U5.2 (A0)
unnamed: U1.9 (QH'), U2.14 (SER)
unnamed: U1.15 (QA), U5.9 (A7)
unnamed: U2.1 (QB), U6.8 (A6)
unnamed: U2.2 (QC), U6.7 (A5)
unnamed: U2.3 (QD), U6.6 (A4)
unnamed: U2.4 (QE), U6.5 (A3)
unnamed: U2.5 (QF), U6.4 (A2)
unnamed: U2.15 (QA), U6.9 (A7)

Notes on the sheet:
+5V Linear Regulator
R2R DAC
POWER SUPPLY
DAC Logic Interface
Pmod
5V Ref
+9V Linear Regulator
-5V Linear Regulator
+3V3 -> +10V Boost
+3V3 -> -6V Inverter
Note: Actual Vout aprox 10.5V
20khz Sallen-Key LP
Buffer
Signal Conditioning + Output
Input Levelshift
Everything except Power Supply, Controls, and Connectors.
GND and GNDA connected on Pmod host.
Variable Attenuation
AC-Coupling
Output
Populate either C/R or JP. (In case DC offs. becomes a problem)

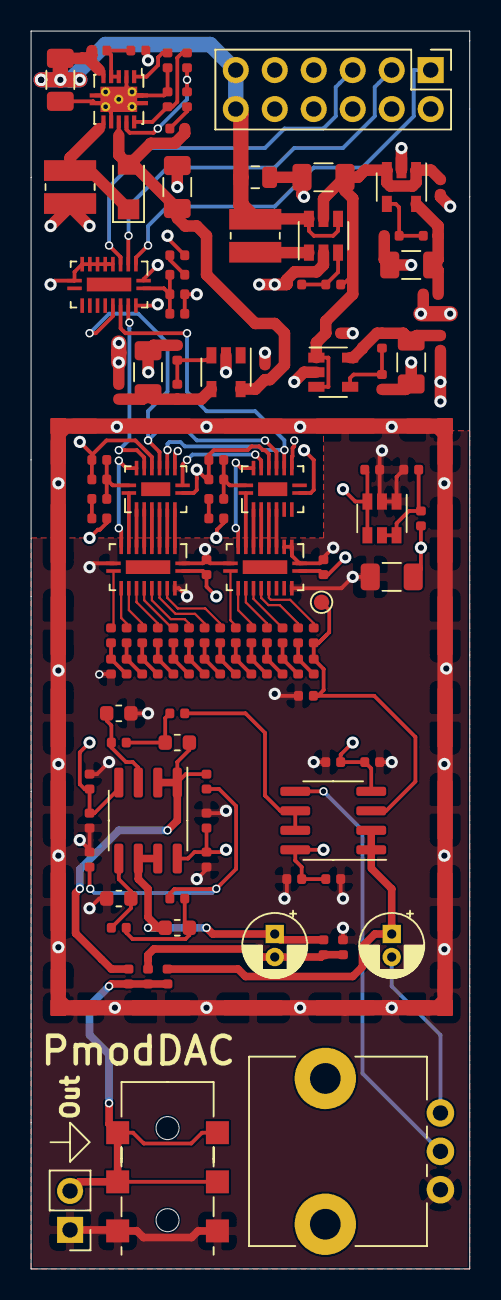
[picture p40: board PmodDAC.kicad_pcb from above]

Board: 4 copper layers, 28.6 x 80.6 mm, 122 parts (0 on the bottom side), 92 nets.

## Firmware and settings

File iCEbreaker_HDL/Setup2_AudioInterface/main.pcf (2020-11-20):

##### Clock and Reset #####
set_io --warn-no-port pin_clk_i      35
set_io --warn-no-port reset_ni       41

##### LEDs #####
set_io --warn-no-port led_txerr_o    40
set_io --warn-no-port led_rxerr_o    39

##### FTDI FT2232H Async Fifo Port B #####
set_io --warn-no-port fifo_d0_io      6
set_io --warn-no-port fifo_d1_io      9
set_io --warn-no-port fifo_d2_io     18
set_io --warn-no-port fifo_d3_io     19
set_io --warn-no-port fifo_d4_io     20
set_io --warn-no-port fifo_d5_io     21
set_io --warn-no-port fifo_d6_io     23
set_io --warn-no-port fifo_d7_io     25

set_io --warn-no-port fifo_nRXF_i    26
set_io --warn-no-port fifo_nTXE_i    27
set_io --warn-no-port fifo_nRD_o     11
set_io --warn-no-port fifo_nWD_o     37

##### PmodADC on PMOD1A #####

# Sample and Hold
set_io --warn-no-port ADC_SH_o       44

# Comparator Input
set_io --warn-no-port ADC_Comp_i     45

# Comparator Latch Output
set_io --warn-no-port ADC_Comp_L_o   47

# ADC DAC Interface 
set_io --warn-no-port ADC_Ser_o      46 # Serial Out
set_io --warn-no-port ADC_SClk_o     48 # Serial Clk
set_io --warn-no-port ADC_LClk_o      3 # Latch Clk


##### PmodDAC on PMOD1B ####

# DAC Interface
set_io --warn-no-port DAC_Ser_o      42 # Serial Out
set_io --warn-no-port DAC_SClk_o     36 # Serial Clk
set_io --warn-no-port DAC_LClk_o     32 # Latch Clk

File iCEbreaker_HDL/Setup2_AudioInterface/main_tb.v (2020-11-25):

`timescale 1ns/1ps
module template_tb();

// ==== Applied Stimuli ====
reg clk_i, reset_ni;
reg [7:0] data_io_set;
reg data_io_oe;

// ==== FPGA IO ====
wire ADC_Ser_o;
wire ADC_SClk_o;
wire ADC_LClk_o;
wire ADC_Comp_i;

wire DAC_Ser_o;
wire DAC_SClk_o;
wire DAC_LClk_o;

wire [7:0] fifo_data_io;
assign fifo_data_io = data_io_oe ? data_io_set : 8'bz;

// ==== Results ====
reg [13:0] result;




// ==== DUT ====
main dut(
	// System
	.pin_clk_i(clk_i),
	.reset_ni(reset_ni),
	
	// ADC Interface
	.ADC_SH_o(),
	.ADC_Ser_o(ADC_Ser_o),
	.ADC_SClk_o(ADC_SClk_o),
	.ADC_LClk_o(ADC_LClk_o),
	.ADC_Comp_i(ADC_Comp_i),
	
	// DAC Interface
	.DAC_Ser_o(DAC_Ser_o),
	.DAC_SClk_o(DAC_SClk_o),
	.DAC_LClk_o(DAC_LClk_o),

	// FIFO Interface
	.fifo_d0_io(fifo_data_io[0]),
	.fifo_d1_io(fifo_data_io[1]),
	.fifo_d2_io(fifo_data_io[2]),
	.fifo_d3_io(fifo_data_io[3]),
	.fifo_d4_io(fifo_data_io[4]),
	.fifo_d5_io(fifo_data_io[5]),
	.fifo_d6_io(fifo_data_io[6]),
	.fifo_d7_io(fifo_data_io[7]),
	
	.fifo_nRXF_i(1'b0),
    .fifo_nTXE_i(1'b0),
    .fifo_nRD_o(),
    .fifo_nWD_o(),
	
	// LEDs
	.led_txerr_o(),
	.led_rxerr_o()
);

// ==== Generate Clock and Reset ====
initial
	begin
		reset_ni = 1'b0;
	#15	reset_ni = 1'b1;
	end
	
initial
	clk_i = 1'b0;
	
always
	begin
	#10 clk_i = ~clk_i;
	force template_tb.dut.pll_36mh.clock_out = clk_i;
	end

// ==== Emulate Response from FIFO ====
initial
	begin
		data_io_oe = 1'b0;
		data_io_set = 8'b0;
		#17800 data_io_oe = 1'b1;
			  data_io_set = 8'hAF;
		#80   data_io_set = 8'h7F;
		#100   data_io_oe = 1'b0;
	end

// ==== Emulate ADC ====
localparam ADC_VAL = 16'h2A52;
assign ADC_Comp_i = adc_shreg_l <= ADC_VAL;
reg[15:0] adc_shreg_s;
reg[15:0] adc_shreg_l;

initial
	begin
	adc_shreg_s <= 0;
	adc_shreg_l <= 0;
	end

// Find rising edges of SCLK and LCLK
reg adc_sclk_old;
reg adc_lclk_old;
always @ (posedge clk_i) begin
	adc_sclk_old <= ADC_SClk_o;
	adc_lclk_old <= ADC_LClk_o;
	end

// Emulate Shift register
always @ (posedge clk_i) begin
	if(ADC_SClk_o & ~adc_sclk_old) begin
		adc_shreg_s <= {adc_shreg_s[14:0],ADC_Ser_o};
		end
	if(ADC_LClk_o & ~adc_lclk_old) begin
		adc_shreg_l <= adc_shreg_s;
		end
	end

// ==== Emulate DAC ====
reg[15:0] dac_shreg_s;
reg[15:0] dac_shreg_l;

initial
	begin
	dac_shreg_s <= 0;
	dac_shreg_l <= 0;
	end
	
// Find rising edges of SCLK and LCLK
reg dac_sclk_old;
reg dac_lclk_old;
always @ (posedge clk_i) begin
	dac_sclk_old <= DAC_SClk_o;
	dac_lclk_old <= DAC_LClk_o;
	end
	
// Emulate Shift register
always @ (posedge clk_i) begin
	if(DAC_SClk_o & ~dac_sclk_old) begin
		dac_shreg_s <= {dac_shreg_s[14:0],DAC_Ser_o};
		end
	if(DAC_LClk_o & ~dac_lclk_old) begin
		dac_shreg_l <= dac_shreg_s;
		end
	end
	
// ==== Handle simulation ====
parameter DURATION = 100000; //x timescale
`define DUMPSTR(x) `"x.vcd`"

initial begin
  $dumpfile(`DUMPSTR(`VCD_OUTPUT));
  $dumpvars(0, template_tb);
   #(DURATION) $display("End of simulation");
  $finish;
end	
	
endmodule

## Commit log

2020-10-11 First draft Schematic
    [PmodADC.kicad_pcb, PmodADC.sch]
2020-10-11 Reworked Power Scheme
    [PmodADC.kicad_pcb, PmodADC.sch]
2020-10-11 PCB v0.0 Done.
    [PmodADC.kicad_pcb, PmodADC.sch]
2020-10-12 Generated Production Files
    [PmodADC-B_Cu.gbr, PmodADC-B_Mask.gbr, PmodADC-B_Paste.gbr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]
2020-10-12 Quickfix PCB v0.1
    [PmodADC-B_Cu.gbr, PmodADC-B_Mask.gbr, PmodADC-B_Paste.gbr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]
2020-10-25 First draft ADC HW working
2020-10-25 First Succesfull ADC and DAC hardware test
2020-10-25 Added TODOs
    [PmodADC.sch]
2020-10-30 Finished Schematic Design
    [PmodADC.sch]
2020-10-31 Added Footprints, fixedup Schematic, Cleanup
    [PmodADC-B_Cu.gbr, PmodADC-B_Mask.gbr, PmodADC-B_Paste.gbr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]
2020-10-31 First Draft Layout PmodADC done
    [PmodADC.kicad_pcb]
2020-10-31 First draft DAC PCB done
    [PmodDAC.kicad_pcb, PmodDAC.sch]
2020-11-01 Generated ADC Produciton Files
    [PmodADC-B_Cu.gbr, PmodADC-B_Mask.gbr, PmodADC-B_Paste.gbr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]
2020-11-01 Added DAC Production Files
    [PmodDAC-B_Cu.gbr, PmodDAC-B_Mask.gbr, PmodDAC-B_Paste.gbr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]
2020-11-02 Added S&H Trace Image
2020-11-04 Added Sample Recording
2020-11-20 Removed Reset (Pin used by FTDI FIFO interface)
    [main.pcf, main_tb.v]
2020-11-20 Fixed Changed Samplerate from debugging
    [SA_ADC.v]
2020-11-21 Updated FIFO test to reflect ADC data rate.
2020-11-25 Reduced on-time for error LEDs
2020-11-25 Confirmed pyserial's read() overhead as problem.
    Moving back to dynamic memory allocation, as it is more
    flexible.
    [Record.py]
2020-11-26 Changed RX LED to shine on success
2020-11-27 Added Information on Driver Setup
2020-11-27 Changed RX led back to error indicator
2020-11-27 Computer playback mostly working
    Still drops a sample or two every second
2020-11-27 Quick ADC Noise Test
2020-11-29 Threaded Packaging during play working.
2020-11-29 Reworked/Fixed ADC Noise test
2020-12-07 Fixed small errors in Play.py
    [Play.py]
